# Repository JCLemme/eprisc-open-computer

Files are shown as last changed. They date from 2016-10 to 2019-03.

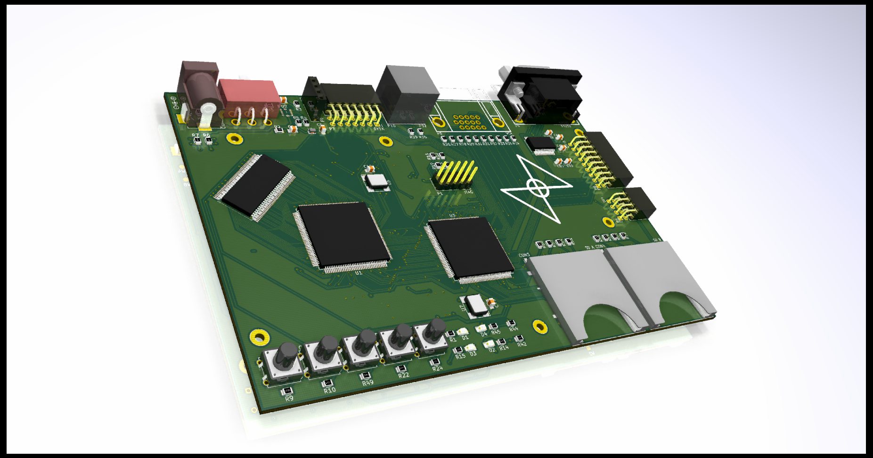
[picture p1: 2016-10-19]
hardware/eprisc_mach/eprisc_mach.png

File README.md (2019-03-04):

# epRISC Open Computer
An open-source computer

# **THIS REPO IS DEPRECATED - check out the "eprisc", "snag", "spasm", and "flail" repositories instead**

---

## Building things
Right now, the system testbench and the assembler can be compiled. Just run the provided Makefiles in their respective directories.

To build the system testbench, you'll need make, Icarus Verilog, and ideally some sort of waveform viewer (like GTKWave). The testbench emulates all of the system's I/O devices, but they aren't connected to anything, so you'll have to read the output waveforms yourself and determine if they're correct or not for debugging. Another thing to pay attention to is the length of time the testbench runs for; running the emulation long enough to catch rare problems might generate VCD files of several hundred megabytes.

To build spasm, you'll need g++, make, and libboost. Everything's been updated for the v5 ISA.

## Developing software
You can use spasm and the system testbench to develop software for the epRISC system. Documentation isn't complete for the new parts of the assembler, but you can use the code in the software/rom/ directory as a starting point. The full list of assembly instructions are in the .cpu file in the software/toolchain/spasm/ directory. 

The assembler can generate binaries in big-endian format and Verilog arrays. Run spasm with the -t flag, replace the contents of the array in the firmware/core/rom_v1r0.v file with the output file generated by spasm, and make the system testbench as directed above. 

## Running on hardware
A Quartus project is provided in the firmware/core directory to run the CPU and its peripherals on an Altera MAX 10 FPGA. You should be able, with little modification, to get the project to synthesize to another Altera FPGA or to another manufacturer's FPGA.

As of 04-05-2017, the computer is running successfully on its development board. If you're interested in running the system on your hardware, please contact me.

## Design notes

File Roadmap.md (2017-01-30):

# Things to do

## ISA
 * Finish defining advanced interrupt controller 
 * Define single-step/breakpoint unit
    
## Machine (Primary)
 * Define machine memory map
 * Write machine file
 * Write supporting I/O for machine file (mainly synchronous RAM/ROM)
 * Write machine testbench
 * Finish defining sysX
 * Write sysX master controller
 * Write sysX slave test unit (for testbench)

## I/O Controller (Auxiliary)
 * Write sysX slave controller
 * Write I/O controller core
 * Merge I/O controller into machine testbench
 * Write UART
 * Integrate UART into I/O controller

## Toolchain
 * Finish assembly format spec
 * Finish instruction set spec
 * Add !str, !pstr to spasm
 * Change !pc to !ip
 * Write ISA v5 core file
 * Retarget spasm to ISA v5 (general)

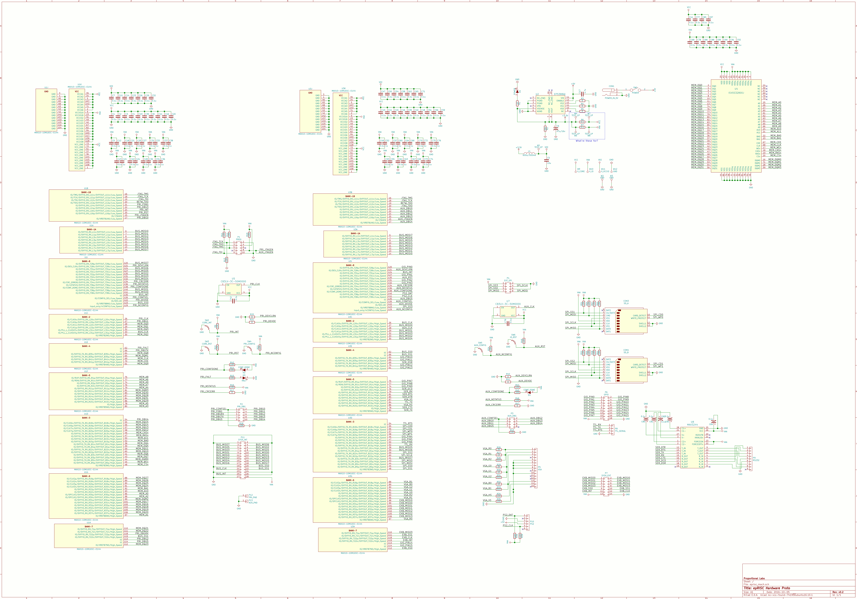
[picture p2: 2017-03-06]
hardware/eprisc_mach/pictureschem.svg/eprisc_mach.png

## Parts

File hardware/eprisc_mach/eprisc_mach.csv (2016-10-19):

Id | Designator | Package | Quantity | Designation | Supplier and ref
1 | C1,C2,C3,C4,C7,C8,C9,C10,C11,C13,C14,C16,C18,C19,C20,C22,C23,C25,C26,C28,C29,C31,C32,C34,C35,C37,C40,C42,C43,C44,C45,C46,C47,C48,C49,C50,C51,C53,C54,C56,C57,C58,C59,C61,C62,C64,C65,C67,C68,C70,C71,C73,C75,C78,C79,C80,C81,C82,C83,C84 | C_0805 | 60 | 0.1u
2 | C5 | C_0805 | 1 | 10u
3 | C6 | C_0805 | 1 | 47u/16v
4 | C12,C15,C21,C24,C27,C30,C33,C36,C38,C39,C41,C52,C55,C60,C63,C66,C69,C72,C74,C76,C77 | C_0805 | 21 | 1u
5 | C17 | C_0805 | 1 | 4.7u
6 | CON1 | BARREL_JACK | 1 | POWER_IN_5V
7 | CON2 | microsd_socket | 1 | SD_INT
8 | CON3 | SD_Card_Receptacle | 1 | SD_A
9 | CON4 | SD_Card_Receptacle | 1 | SD_B
10 | D1 | LED_0805 | 1 | GREEN
11 | D2,D4 | LED_0805 | 2 | CONF_DONE
12 | D3 | LED_0805 | 1 | HALT
13 | L1 | inductor_smd_4.8x2.8mm | 1 | 600o/500mA
14 | L2,L3 | inductor_smd_0805 | 2 | FERRITE_BEAD
15 | P5 | DB_15F-VGA | 1 | VGA
16 | P6 | Socket_Strip_Angled_2x09 | 1 | GPIO
17 | P7 | Socket_Strip_Angled_2x07 | 1 | SYSX_EXT
18 | P8 | Socket_Strip_Straight_1x04 | 1 | TTL_SERIAL
19 | P9 | DB_9F | 1 | RS232
20 | P10 | minidin-8 | 1 | PS2
21 | R1,R13,R14,R15,R16,R17,R27,R30,R32,R38,R45,R46,R47 | R_0805 | 13 | 1K
22 | R2 | R_0805 | 1 | DNI
23 | R3,R4,R5,R8,R20,R21,R23,R40,R41 | R_0805 | 9 | 0
24 | R6,R7 | R_0805 | 2 | 0.1
25 | R9,R10,R42,R44 | R_0805 | 4 | 3.3K
26 | R11,R12,R18,R19,R22,R24,R25,R36,R37,R39,R43,R48,R49 | R_0805 | 13 | 10K
27 | R26,R29 | R_0805 | 2 | 2K
28 | R28,R31,R33 | R_0805 | 3 | 510
29 | R34,R35 | R_0805 | 2 | 100
30 | R50,R51,R52,R53,R54,R55,R56,R57,R58,R59,R60,R61 | R_0805 | 12 | 50K
31 | SW2 | smd_push2 | 1 | CORE_INT
32 | SW3 | smd_push2 | 1 | CORE_RST
33 | SW4 | smd_push2 | 1 | PRI_CONFIG
34 | SW5 | smd_push2 | 1 | AUX_CONFIG
35 | SW6 | smd_push2 | 1 | IO_RST
36 | U1,U6 | LQFP-144_20x20mm_Pitch0.5mm | 2 | MAX10-10M16SA-E144
37 | U2 | QFN-16-ALTERA | 1 | EP5388QI
38 | U3 | SOT-23 | 1 | MCP1525
39 | U4 | TSOP-86 | 1 | IS45S32800J
40 | U5,U7 | CRYSTAL_CTS | 2 | CB3LV-3C-50M0000
41 | U8 | SSOP-28_5.3x10.2mm_Pitch0.65mm | 1 | MAX3244
42 | W1,W4,W5,W7,W8 | Measurement_Point_Round-SMD-Pad_Small | 5 | TEST_1P
43 | W2,W3,W6,W12 | Measurement_Point_Round-SMD-Pad_Small | 4 | GND
44 | W9 | Measurement_Point_Round-SMD-Pad_Small | 1 | V_CORE
45 | W10 | Measurement_Point_Round-SMD-Pad_Small | 1 | V_IO
46 | W11 | Measurement_Point_Round-SMD-Pad_Small | 1 | V_VCCIO
47 | W13 | Measurement_Point_Round-SMD-Pad_Small | 1 | GNDA
48 | W14 | Measurement_Point_Round-SMD-Pad_Small | 1 | V_REF
49 | P1 | SMD_STRIP_10 | 1 | PRI_PROG
50 | P2 | SMD_STRIP_10 | 1 | PRI_DBG
51 | P3 | SMD_STRIP_8 | 1 | AUX_DBG
52 | P4 | SMD_STRIP_10 | 1 | AUX_PROG
53 | P11 | SMD_STRIP_28 | 1 | SYSX_INT
54 | SW1 | SW_Micro_SPST_Angled | 1 | POWER

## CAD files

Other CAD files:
firmware/io/aux_project/output_files/stp1.stp

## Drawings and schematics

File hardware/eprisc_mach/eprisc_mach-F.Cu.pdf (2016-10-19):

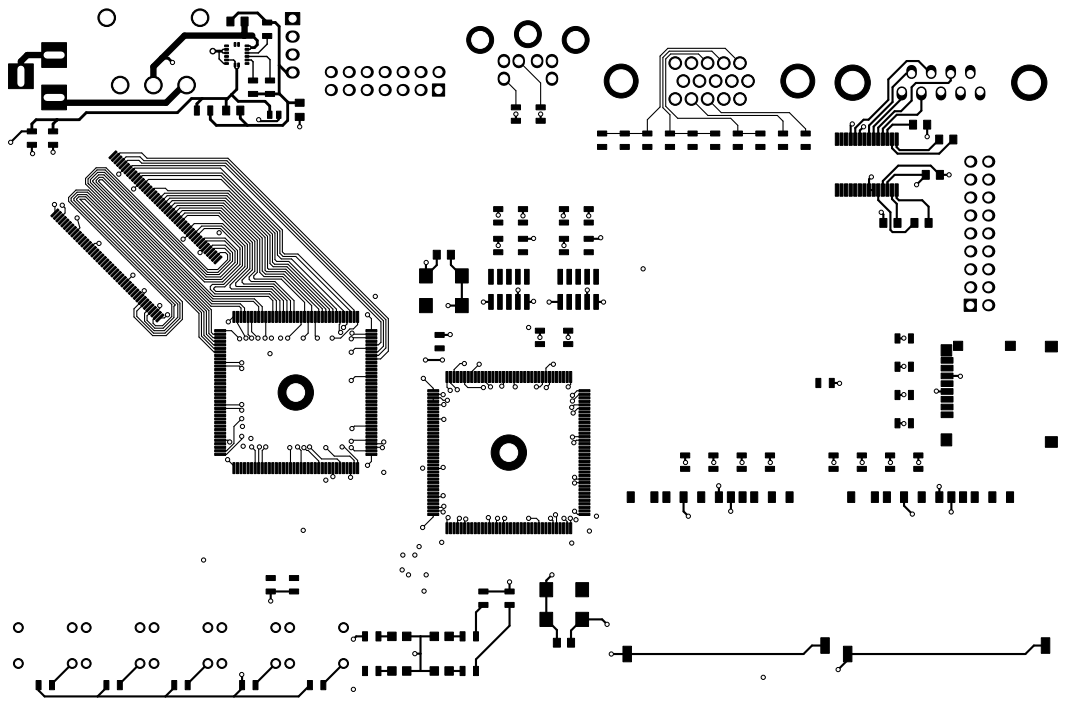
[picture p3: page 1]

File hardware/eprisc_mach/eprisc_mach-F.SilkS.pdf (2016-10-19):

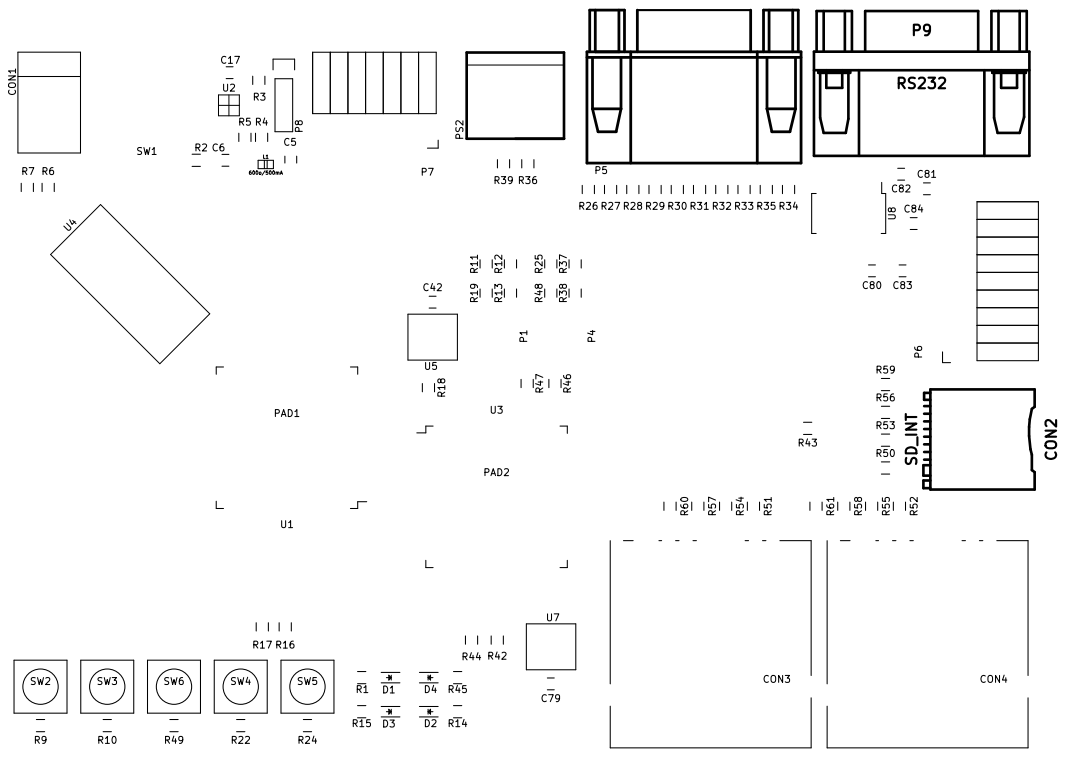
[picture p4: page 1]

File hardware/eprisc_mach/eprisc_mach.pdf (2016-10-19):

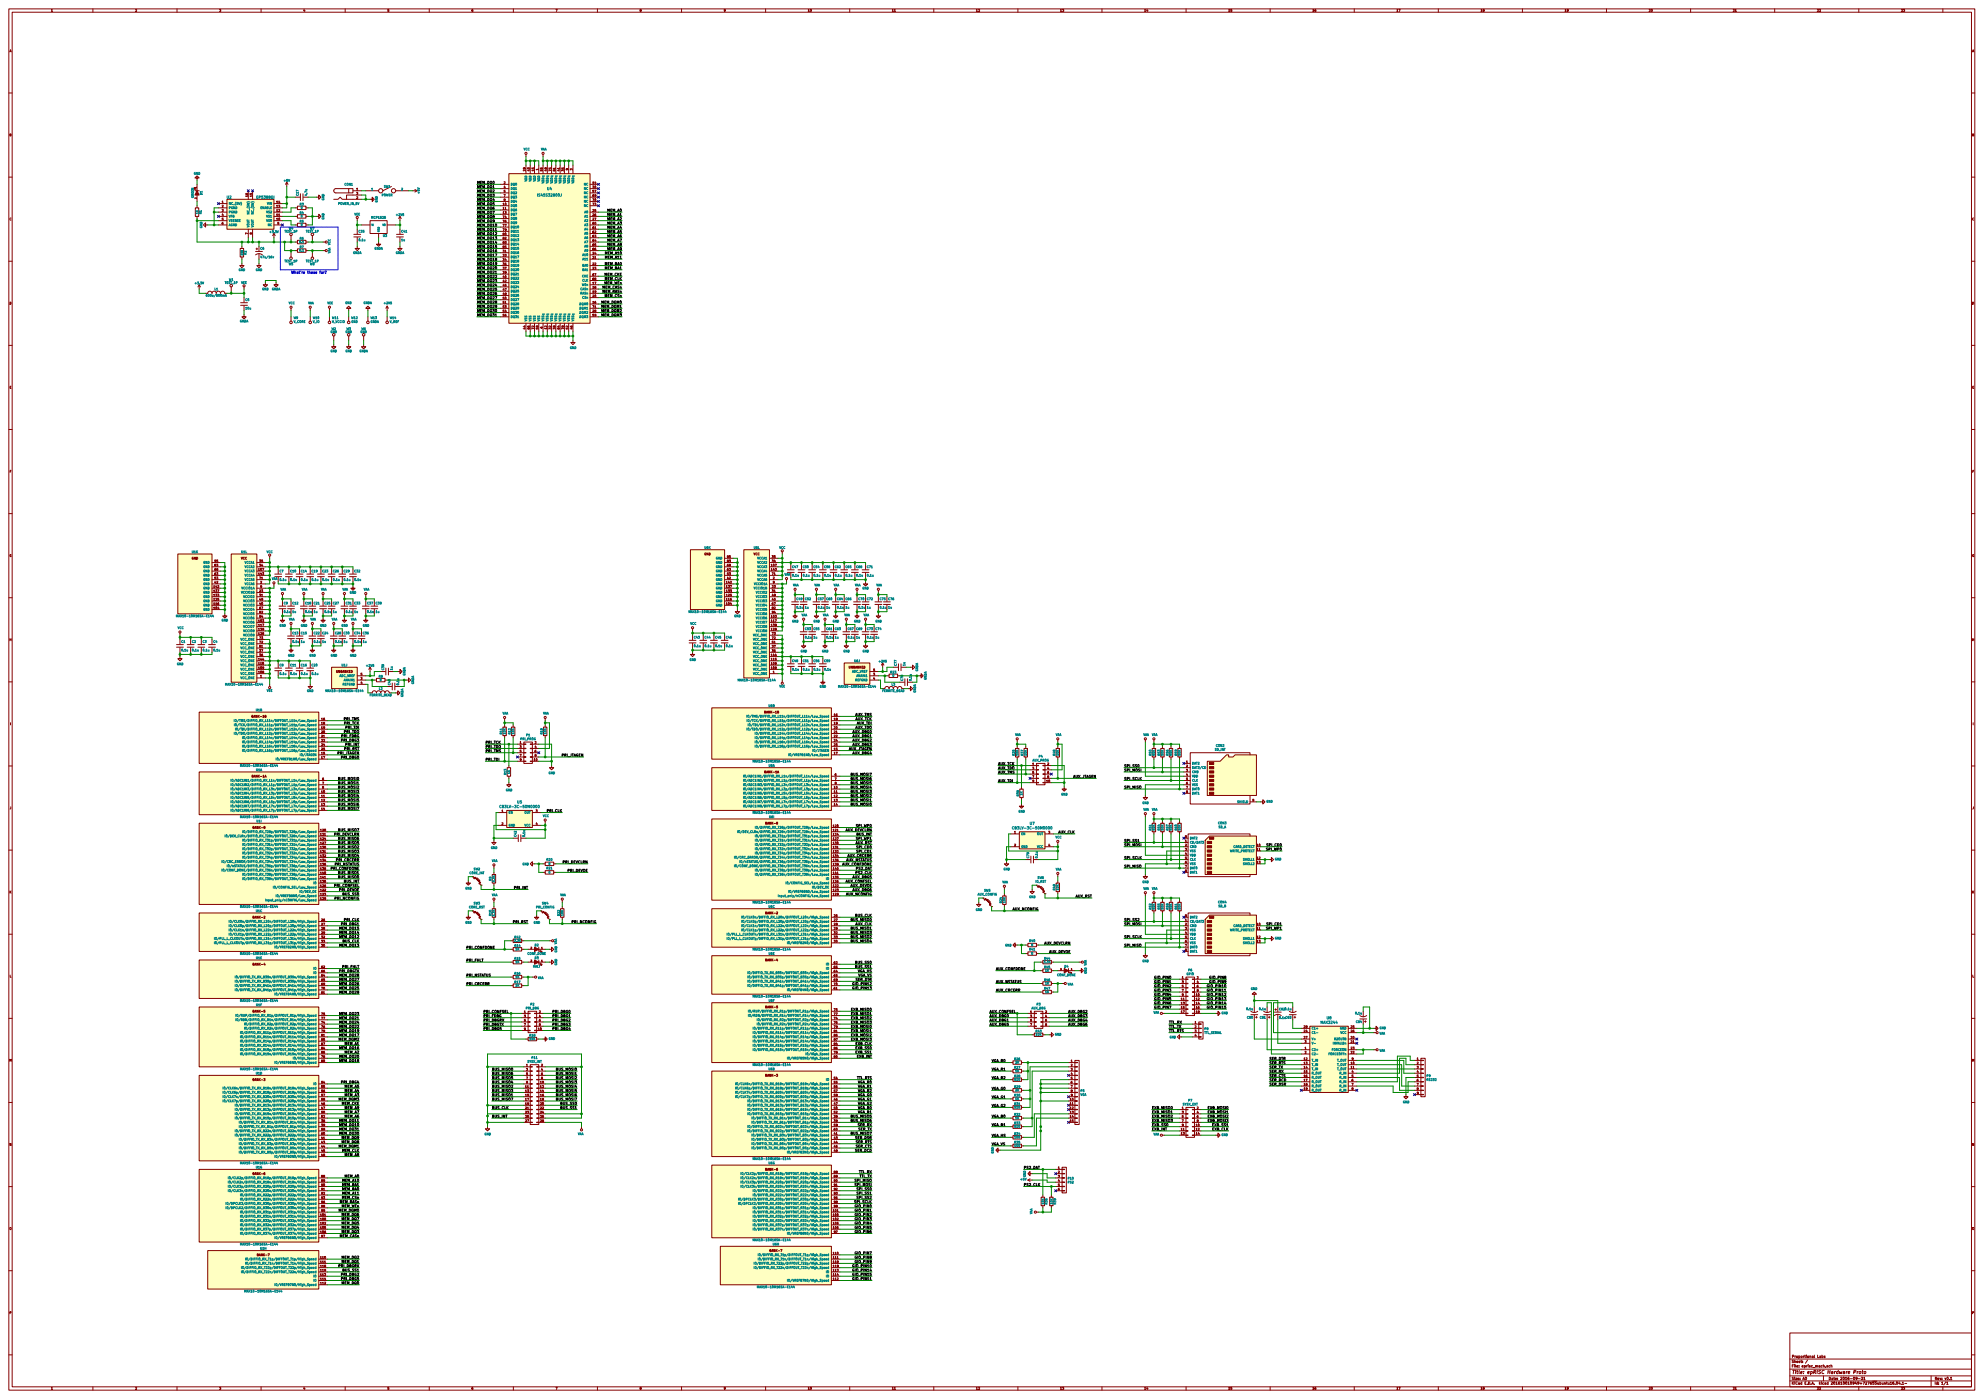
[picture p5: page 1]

File: eprisc_mach.sch Sheet: / Proportional Labs

Id: 1/1 Title: epRISC Hardware Proto

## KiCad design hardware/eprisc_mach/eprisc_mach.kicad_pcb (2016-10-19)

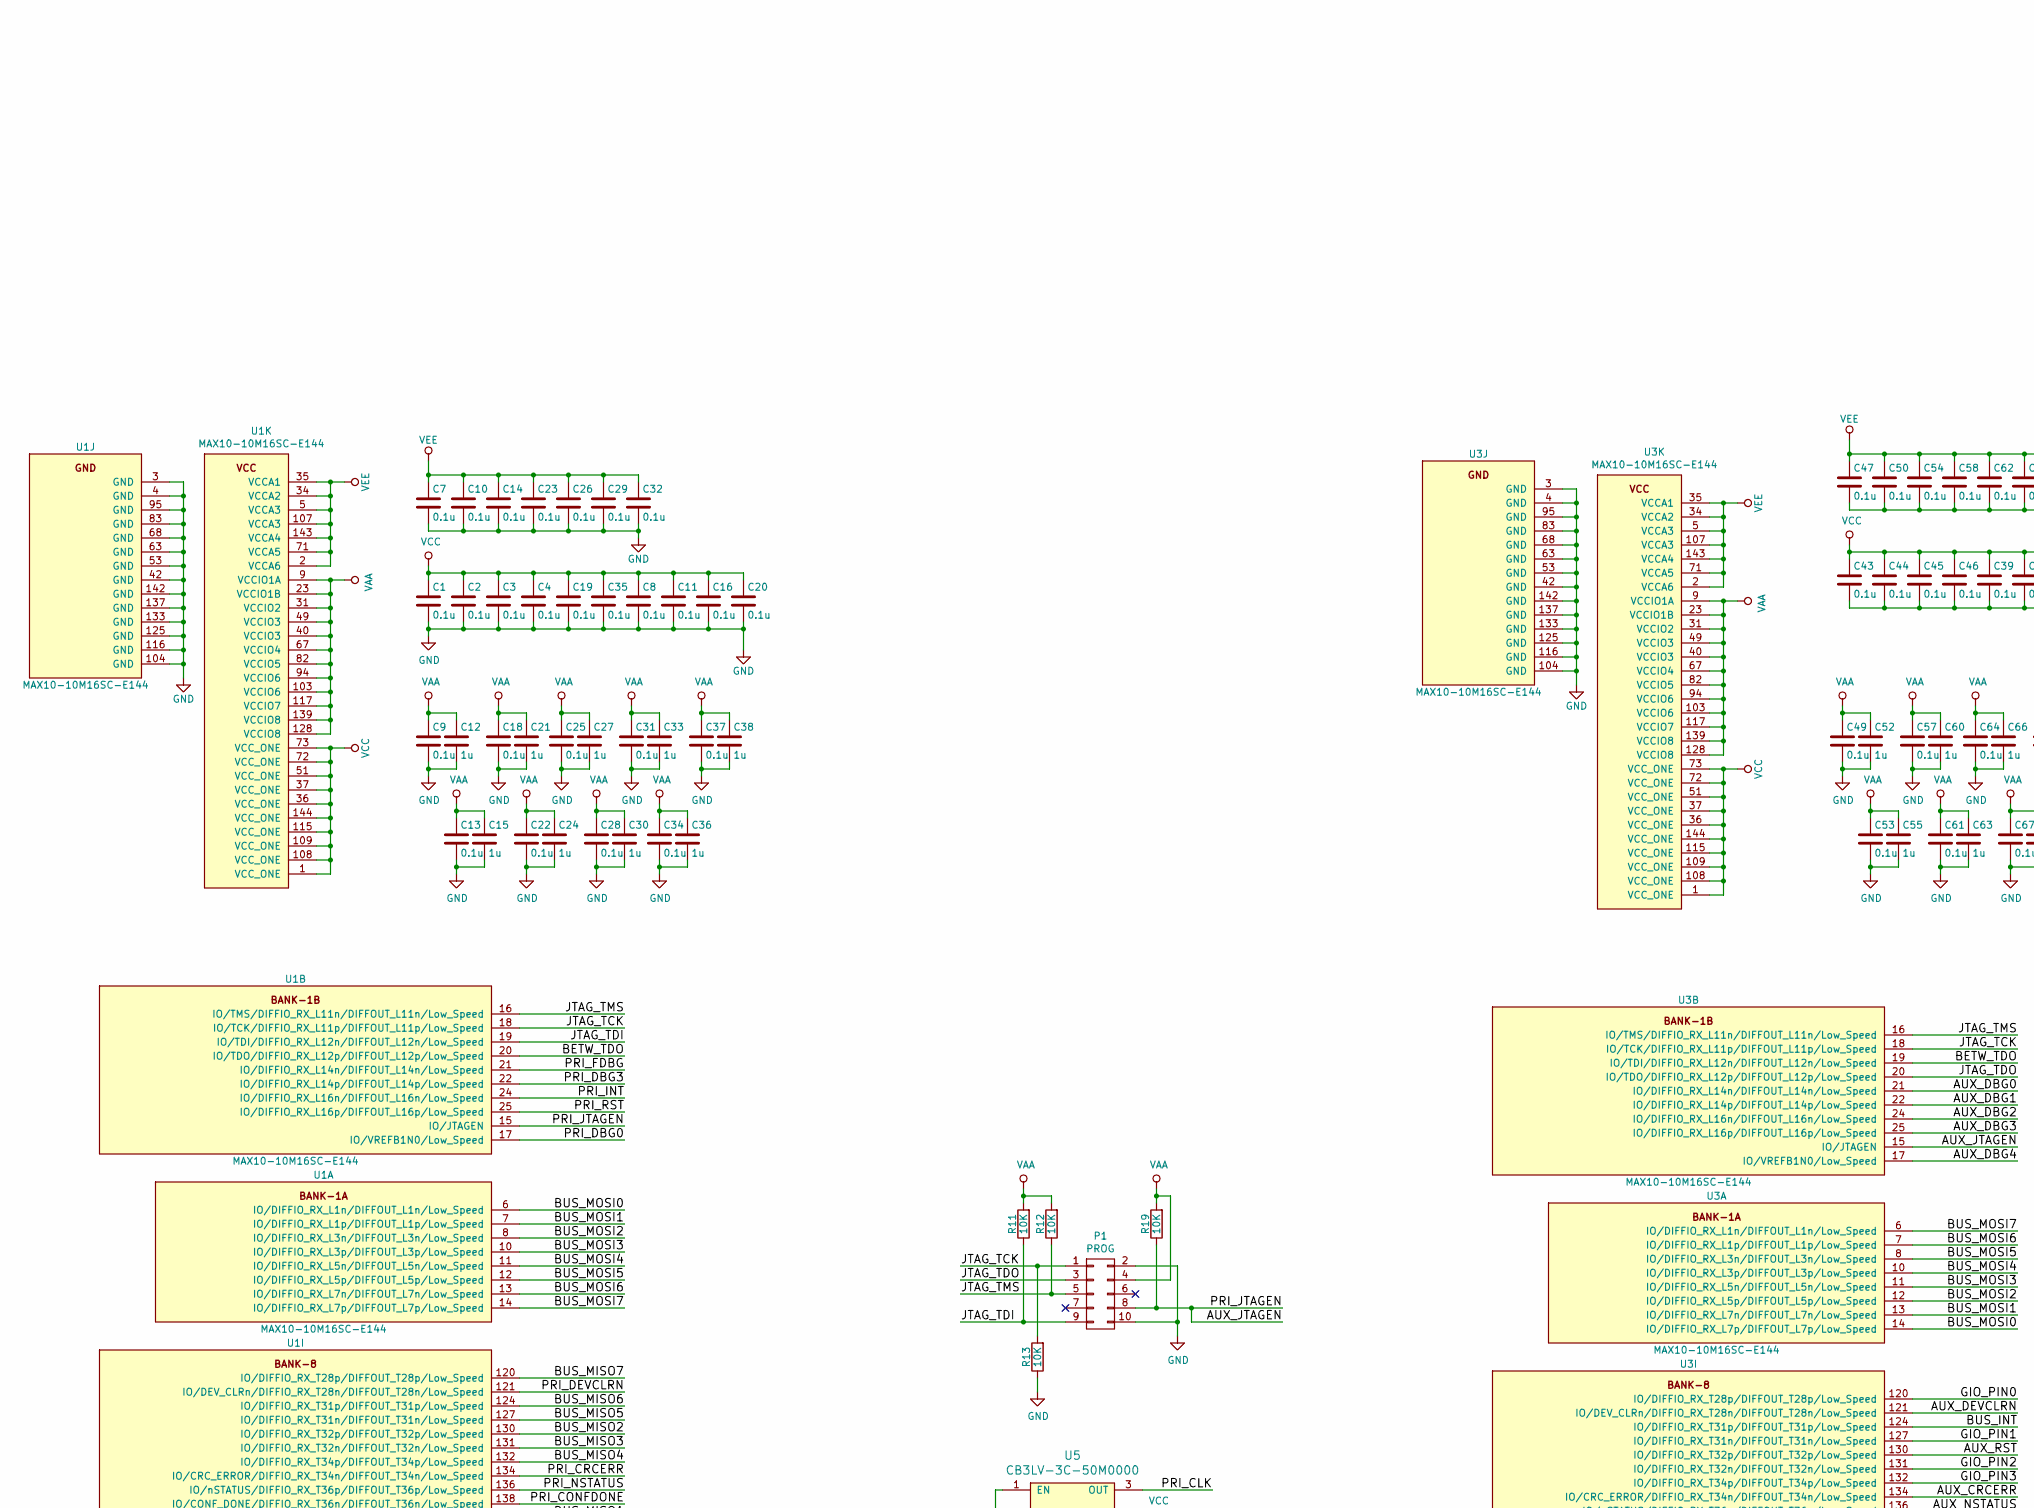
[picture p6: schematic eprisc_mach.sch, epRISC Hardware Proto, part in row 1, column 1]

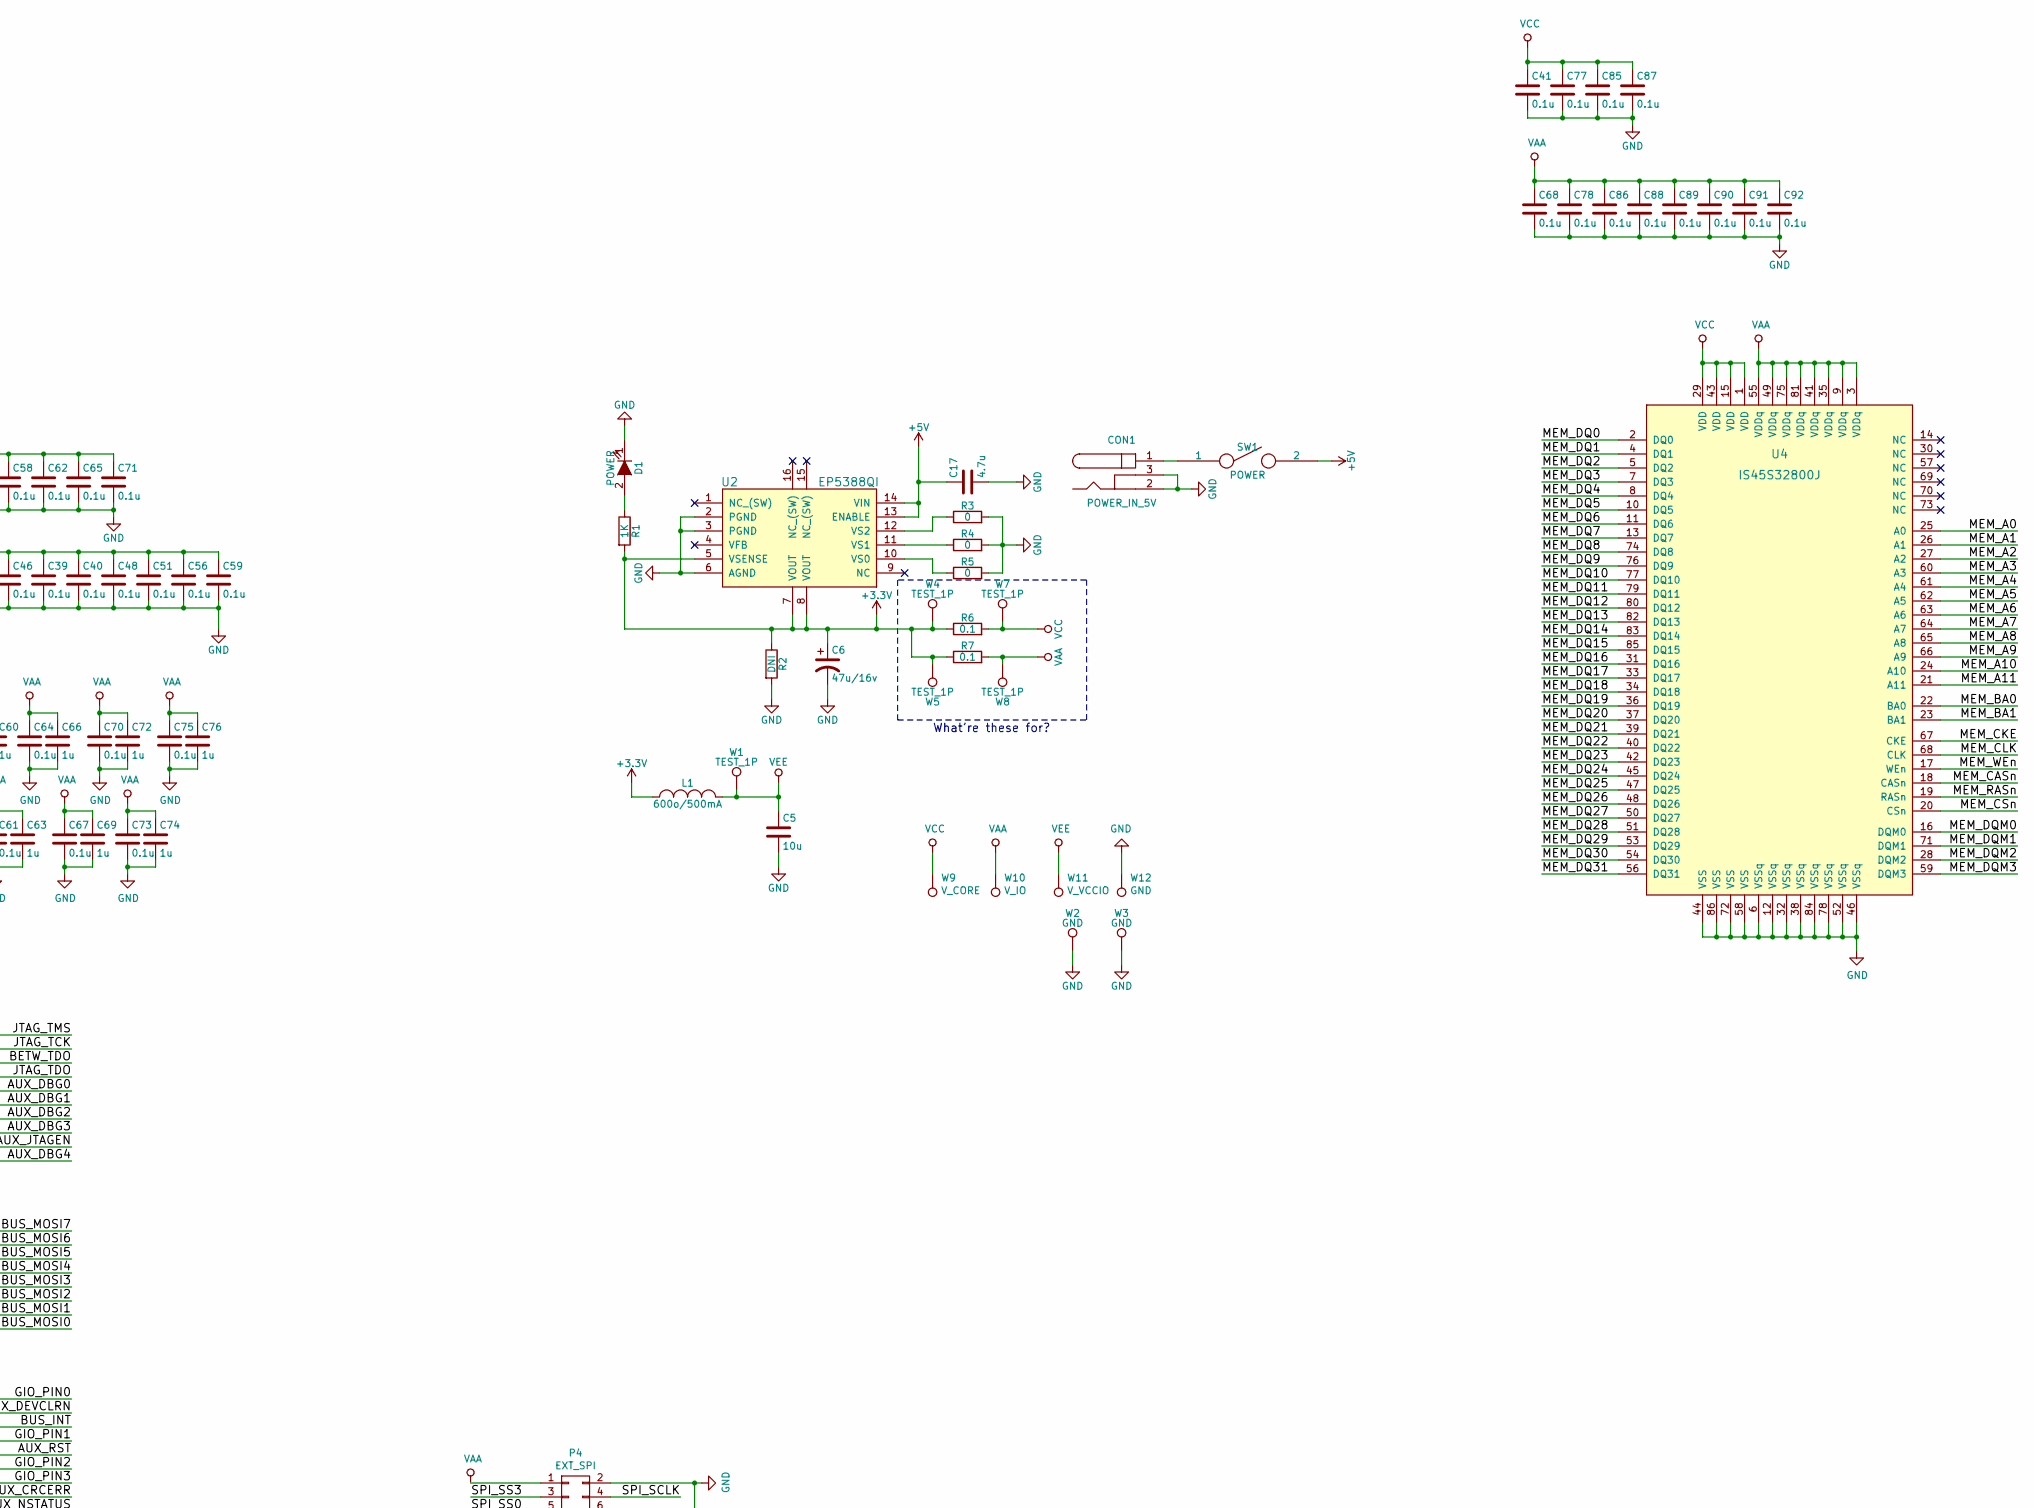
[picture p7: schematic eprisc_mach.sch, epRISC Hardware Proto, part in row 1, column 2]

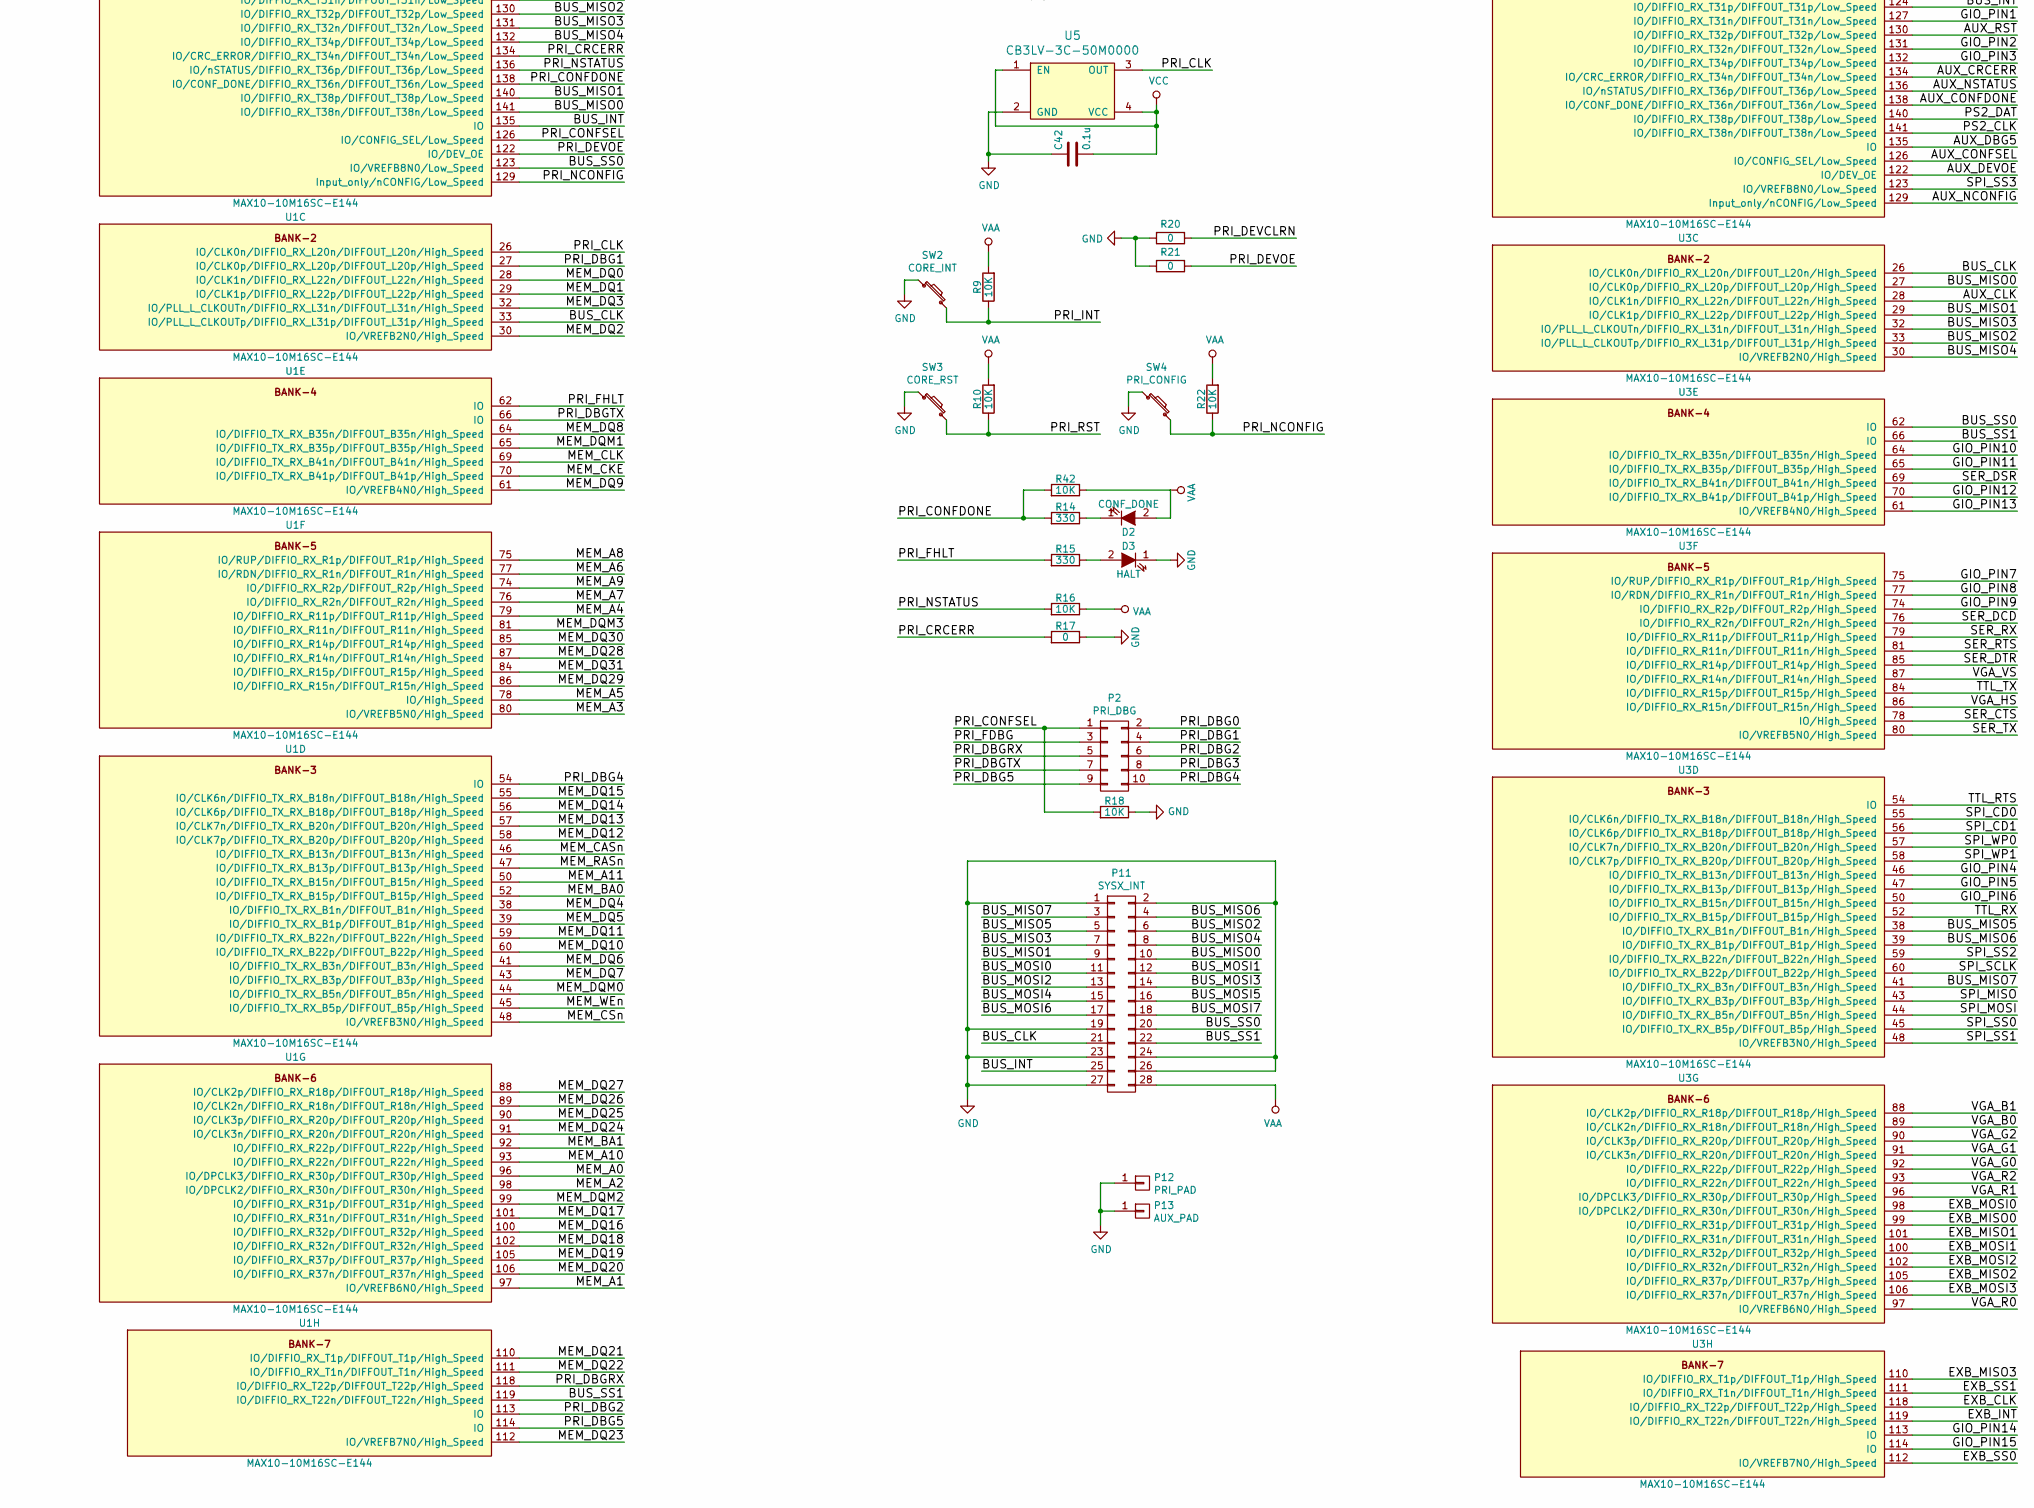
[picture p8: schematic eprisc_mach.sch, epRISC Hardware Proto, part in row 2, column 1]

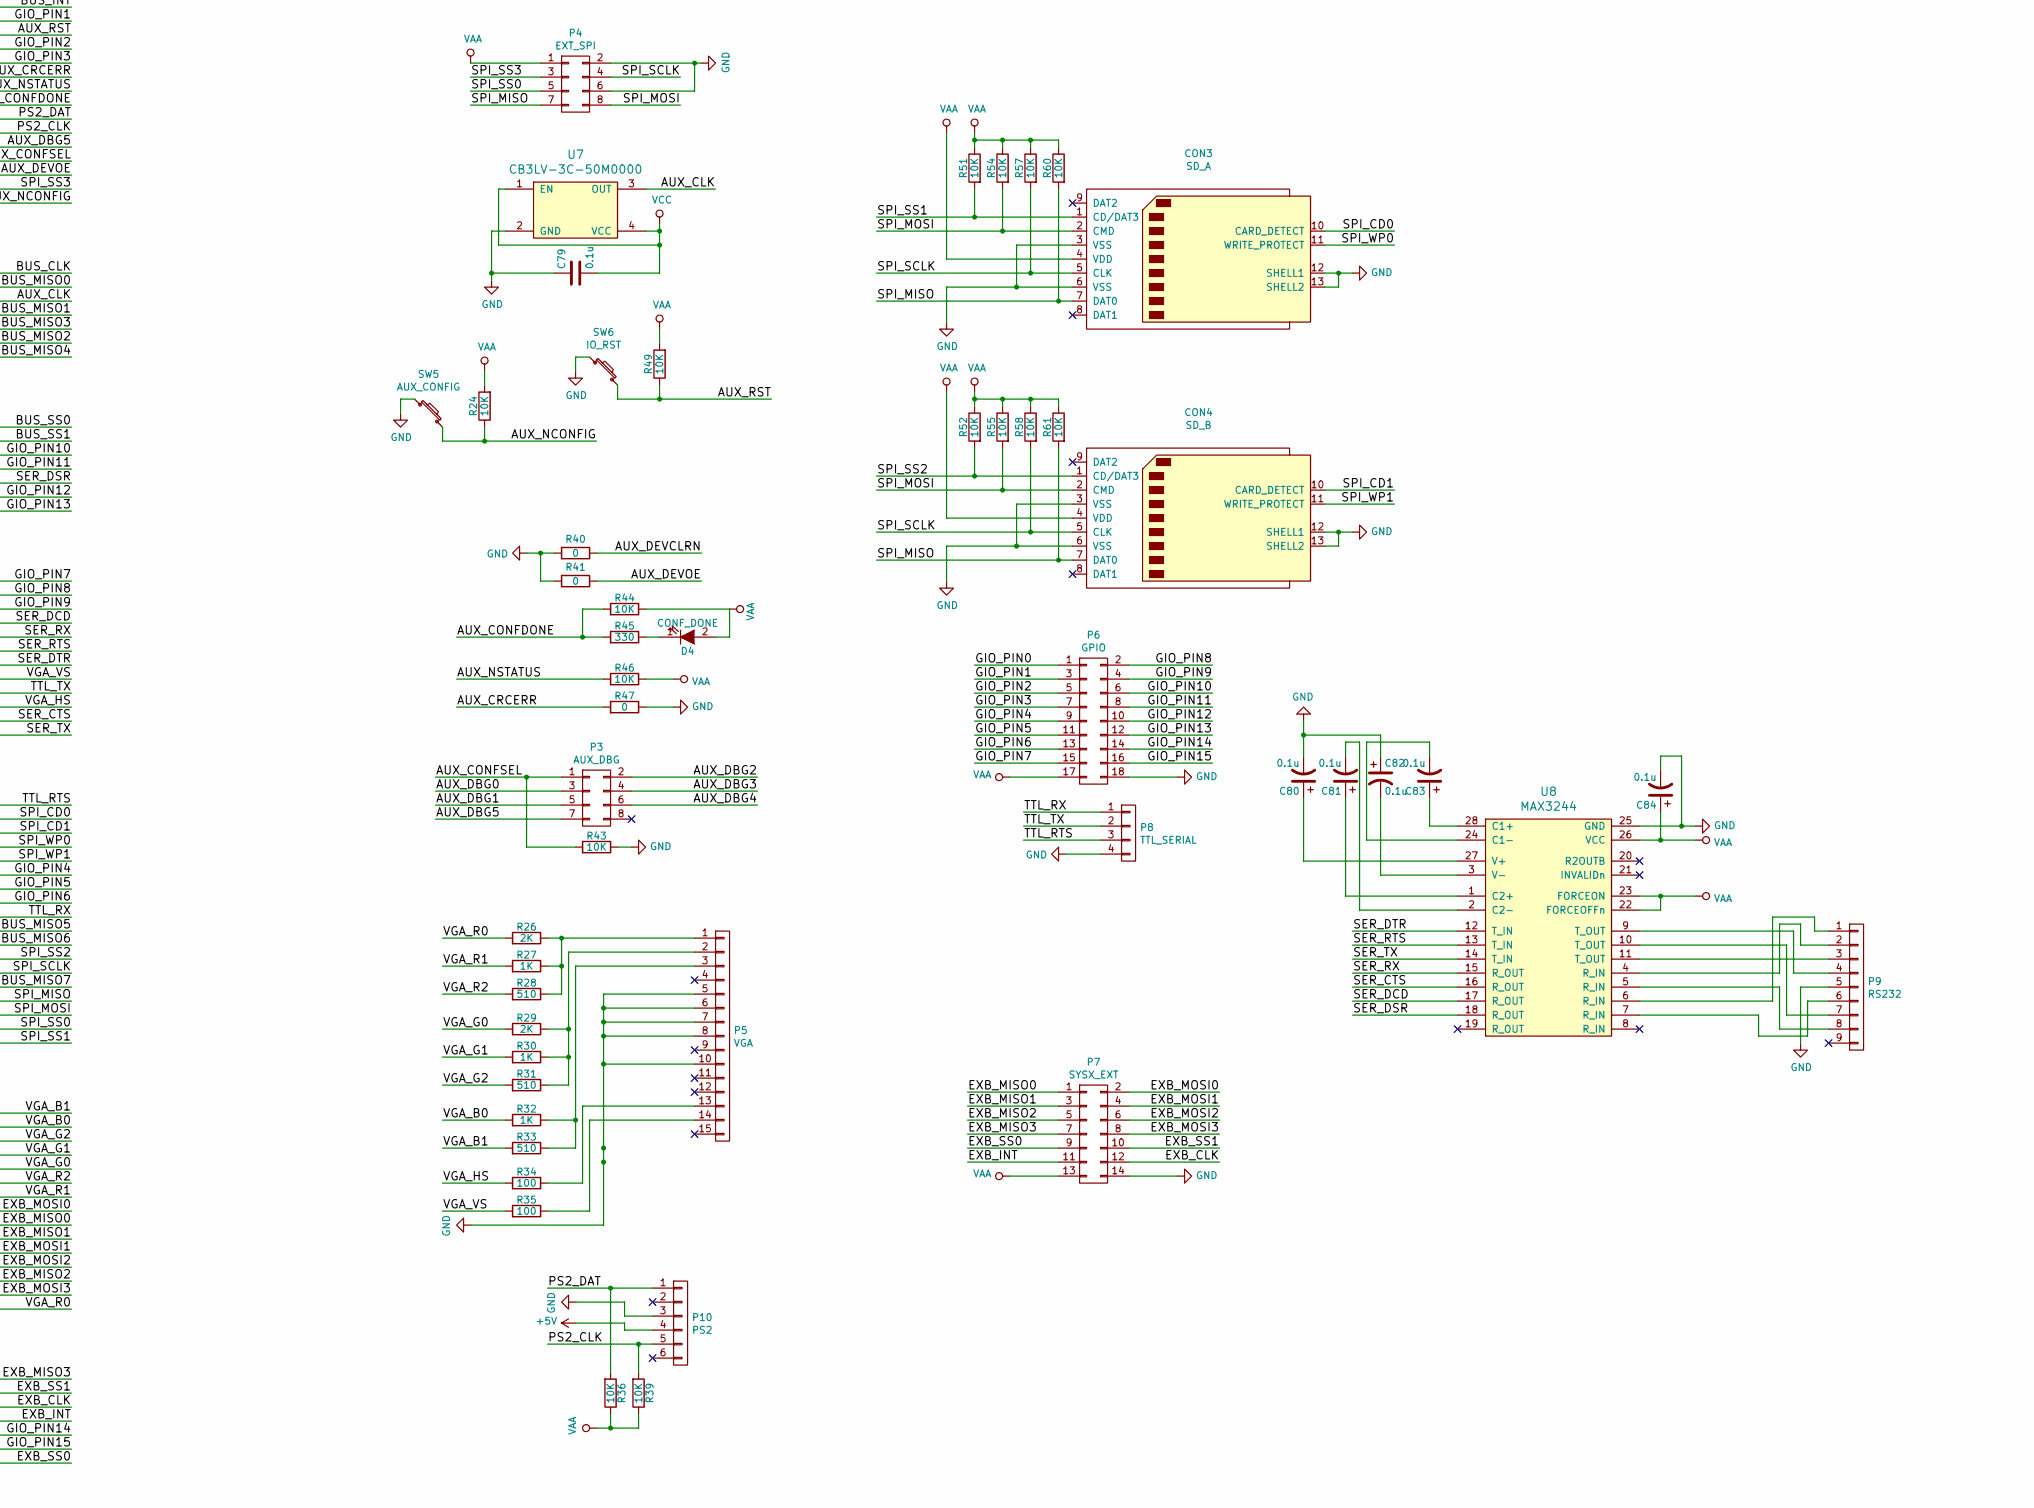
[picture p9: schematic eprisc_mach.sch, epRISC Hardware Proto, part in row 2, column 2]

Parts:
C1, C2, C3, C4, C7, C8, C9, C10, C11, C13, C14, C16, C18, C19, C20, C22, C23, C25, C26, C28, C29, C31, C32, C34, C35, C37, C39, C40, C41, C42, C43, C44, C45, C46, C47, C48, C49, C50, C51, C53, C54, C56, C57, C58, C59, C61, C62, C64, C65, C67, C68, C70, C71, C73, C75, C77, C78, C79, C80, C81, C82, C83, C84, C85, C86, C87, C88, C89, C90, C91, C92: 0.1u; C_0805
C5: 10u; C_0805
C6: 47u/16v; C_0805
C12, C15, C21, C24, C27, C30, C33, C36, C38, C52, C55, C60, C63, C66, C69, C72, C74, C76: 1u; C_0805
C17: 4.7u; C_0805
CON1: POWER_IN_5V; BARREL_JACK
CON3: SD_A; SD_Card_Receptacle
CON4: SD_B; SD_Card_Receptacle
D1: POWER; LED_0805
D2, D4: CONF_DONE; LED_0805
D3: HALT; LED_0805
L1: 600o/500mA; inductor_smd_0603
P1: PROG; Pin_Header_Straight_2x05
P2: PRI_DBG; SMD_STRIP_10
P3: AUX_DBG; SMD_STRIP_8
P4: EXT_SPI; Socket_Strip_Angled_2x04
P5: VGA; DB15F-VGA-AMP
P6: GPIO; Socket_Strip_Angled_2x09
P7: SYSX_EXT; Socket_Strip_Angled_2x07
P8: TTL_SERIAL; Socket_Strip_Straight_1x04
P9: RS232; DB_9F
P10: PS2; 00JG-MiniDin6
P11: SYSX_INT; SMD_STRIP_28
P12: PRI_PAD; MountingHole_2.5mm_Pad
P13: AUX_PAD; MountingHole_2.5mm_Pad
R1, R27, R30, R32: 1K; R_0805
R2: DNI; R_0805
R3, R4, R5, R17, R20, R21, R40, R41, R47: 0; R_0805
R6, R7: 0.1; R_0805
R9, R10, R11, R12, R13, R16, R18, R19, R22, R24, R36, R39, R42, R43, R44, R46, R49, R51, R52, R54, R55, R57, R58, R60, R61: 10K; R_0805
R14, R15, R45: 330; R_0805
R26, R29: 2K; R_0805
R28, R31, R33: 510; R_0805
R34, R35: 100; R_0805
SW1: POWER; SW_SLIDE_PWR
SW2: CORE_INT; SW_PUSH_SMALL
SW3: CORE_RST; SW_PUSH_SMALL
SW4: PRI_CONFIG; SW_PUSH_SMALL
SW5: AUX_CONFIG; SW_PUSH_SMALL
SW6: IO_RST; SW_PUSH_SMALL
U1, U3: MAX10-10M16SC-E144; LQFP-144_20x20mm_Pitch0.5mm
U2: EP5388QI; QFN-16-ALTERA
U4: IS45S32800J; TSOP-86
U5, U7: CB3LV-3C-50M0000; CRYSTAL_CTS
U8: MAX3244; SSOP-28_5.3x10.2mm_Pitch0.65mm
W1, W4, W5, W7, W8: TEST_1P; Measurement_Point_Round-SMD-Pad_Small
W2, W3, W12: GND; Measurement_Point_Round-SMD-Pad_Small
W9: V_CORE; Measurement_Point_Round-SMD-Pad_Small
W10: V_IO; Measurement_Point_Round-SMD-Pad_Small
W11: V_VCCIO; Measurement_Point_Round-SMD-Pad_Small

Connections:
+3V3: C6.1, L1.1, R1.2, R2.1, R6.1, R7.1, U2.5 (VSENSE), U2.7 (VOUT), U2.8 (VOUT), W4.1, W5.1
+5V: C17.1, P10.4, SW1.2, U2.13 (ENABLE), U2.14 (VIN)
/AUX_CLK: U3.28 (IO/CLK1n/DIFFIO_RX_L22n/DIFFOUT_L22n/Hi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), U7.3 (OUT)
/AUX_CONFDONE: R44.2, R45.2, U3.138 (IO/CONF_DONE/DIFFIO_RX_T36n/DIFFOUT_T36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)
/AUX_CONFSEL: P3.1, R43.2, U3.126 (IO/CONFIG_SEL/Low_Speed)
/AUX_CRCERR: R47.2, U3.134 (IO/CRC_ERROR/DIFFIO_RX_T34n/DIFFOUT_T34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)
/AUX_DBG0: P3.3, U3.21 (IO/DIFFIO_RX_L14n/DIFFOUT_L14n/Low_Speed)
/AUX_DBG1: P3.5, U3.22 (IO/DIFFIO_RX_L14p/DIFFOUT_L14p/Low_Speed)
/AUX_DBG2: P3.2, U3.24 (IO/DIFFIO_RX_L16n/DIFFOUT_L16n/Low_Speed)
/AUX_DBG3: P3.4, U3.25 (IO/DIFFIO_RX_L16p/DIFFOUT_L16p/Low_Speed)
/AUX_DBG4: P3.6, U3.17 (IO/VREFB1N0/Low_Speed)
/AUX_DBG5: P3.7, U3.135 (IO)
/AUX_DEVCLRN: R40.1, U3.121 (IO/DEV_CLRn/DIFFIO_RX_T28n/DIFFOUT_T28n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)
/AUX_DEVOE: R41.1, U3.122 (IO/DEV_OE)
/AUX_JTAGEN: P1.8, R19.1, U1.15 (IO/JTAGEN), U3.15 (IO/JTAGEN)
/AUX_NCONFIG: R24.1, SW5.2, U3.129 (Input_only/nCONFIG/Low_Speed)
/AUX_NSTATUS: R46.2, U3.136 (IO/nSTATUS/DIFFIO_RX_T36p/DIFFOUT_T36p/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)
/AUX_RST: R49.1, SW6.2, U3.130 (IO/DIFFIO_RX_T32p/DIFFOUT_T32p/Low_Speed)
/BETW_TDO: U1.20 (IO/TDO/DIFFIO_RX_L12p/DIFFOUT_L12p/Low_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), U3.19 (IO/TDI/DIFFIO_RX_L12n/DIFFOUT_L12n/Low_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)
/BUS_CLK: P11.21, U1.33 (IO/PLL_L_CLKOUTp/DIFFIO_RX_L31p/DIFFOUT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), U3.26 (IO/CLK0n/DIFFIO_RX_L20n/DIFFOUT_L20n/Hi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)
/BUS_INT: P11.25, U1.135 (IO), U3.124 (IO/DIFFIO_RX_T31p/DIFFOUT_T31p/Low_Speed)
/BUS_MISO0: P11.10, U1.141 (IO/DIFFIO_RX_T38n/DIFFOUT_T38n/Low_Speed), U3.27 (IO/CLK0p/DIFFIO_RX_L20p/DIFFOUT_L20p/Hi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)
/BUS_MISO1: P11.9, U1.140 (IO/DIFFIO_RX_T38p/DIFFOUT_T38p/Low_Speed), U3.29 (IO/CLK1p/DIFFIO_RX_L22p/DIFFOUT_L22p/Hi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)
/BUS_MISO2: P11.6, U1.130 (IO/DIFFIO_RX_T32p/DIFFOUT_T32p/Low_Speed), U3.33 (IO/PLL_L_CLKOUTp/DIFFIO_RX_L31p/DIFFOUT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)
/BUS_MISO3: P11.7, U1.131 (IO/DIFFIO_RX_T32n/DIFFOUT_T32n/Low_Speed), U3.32 (IO/PLL_L_CLKOUTn/DIFFIO_RX_L31n/DIFFOUT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)
/BUS_MISO4: P11.8, U1.132 (IO/DIFFIO_RX_T34p/DIFFOUT_T34p/Low_Speed), U3.30 (IO/VREFB2N0/High_Speed)
/BUS_MISO5: P11.5, U1.127 (IO/DIFFIO_RX_T31n/DIFFOUT_T31n/Low_Speed), U3.38 (IO/DIFFIO_TX_RX_B1n/DIFFOUT_B1n/High_Sp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)
/BUS_MISO6: P11.4, U1.124 (IO/DIFFIO_RX_T31p/DIFFOUT_T31p/Low_Speed), U3.39 (IO/DIFFIO_TX_RX_B1p/DIFFOUT_B1p/High_Sp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)
/BUS_MISO7: P11.3, U1.120 (IO/DIFFIO_RX_T28p/DIFFOUT_T28p/Low_Speed), U3.41 (IO/DIFFIO_TX_RX_B3n/DIFFOUT_B3n/High_Sp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)
/BUS_MOSI0: P11.11, U1.6 (IO/DIFFIO_RX_L1n/DIFFOUT_L1n/Low_Speed), U3.14 (IO/DIFFIO_RX_L7p/DIFFOUT_L7p/Low_Speed)
/BUS_MOSI1: P11.12, U1.7 (IO/DIFFIO_RX_L1p/DIFFOUT_L1p/Low_Speed), U3.13 (IO/DIFFIO_RX_L7n/DIFFOUT_L7n/Low_Speed)
/BUS_MOSI2: P11.13, U1.8 (IO/DIFFIO_RX_L3n/DIFFOUT_L3n/Low_Speed), U3.12 (IO/DIFFIO_RX_L5p/DIFFOUT_L5p/Low_Speed)
/BUS_MOSI3: P11.14, U1.10 (IO/DIFFIO_RX_L3p/DIFFOUT_L3p/Low_Speed), U3.11 (IO/DIFFIO_RX_L5n/DIFFOUT_L5n/Low_Speed)
/BUS_MOSI4: P11.15, U1.11 (IO/DIFFIO_RX_L5n/DIFFOUT_L5n/Low_Speed), U3.10 (IO/DIFFIO_RX_L3p/DIFFOUT_L3p/Low_Speed)
/BUS_MOSI5: P11.16, U1.12 (IO/DIFFIO_RX_L5p/DIFFOUT_L5p/Low_Speed), U3.8 (IO/DIFFIO_RX_L3n/DIFFOUT_L3n/Low_Speed)
/BUS_MOSI6: P11.17, U1.13 (IO/DIFFIO_RX_L7n/DIFFOUT_L7n/Low_Speed), U3.7 (IO/DIFFIO_RX_L1p/DIFFOUT_L1p/Low_Speed)
/BUS_MOSI7: P11.18, U1.14 (IO/DIFFIO_RX_L7p/DIFFOUT_L7p/Low_Speed), U3.6 (IO/DIFFIO_RX_L1n/DIFFOUT_L1n/Low_Speed)
/BUS_SS0: P11.20, U1.123 (IO/VREFB8N0/Low_Speed), U3.62 (IO)
/BUS_SS1: P11.22, U1.119 (IO/DIFFIO_RX_T22n/DIFFOUT_T22n/High_Spe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), U3.66 (IO)
/EXB_CLK: P7.12, U3.118 (IO/DIFFIO_RX_T22p/DIFFOUT_T22p/High_Spe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)
/EXB_INT: P7.11, U3.119 (IO/DIFFIO_RX_T22n/DIFFOUT_T22n/High_Spe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)
/EXB_MISO0: P7.1, U3.99 (IO/DIFFIO_RX_R31p/DIFFOUT_R31p/High_Spe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)
/EXB_MISO1: P7.3, U3.101 (IO/DIFFIO_RX_R31n/DIFFOUT_R31n/High_Spe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)
/EXB_MISO2: P7.5, U3.105 (IO/DIFFIO_RX_R37p/DIFFOUT_R37p/High_Spe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)
/EXB_MISO3: P7.7, U3.110 (IO/DIFFIO_RX_T1p/DIFFOUT_T1p/High_Speed)
/EXB_MOSI0: P7.2, U3.98 (IO/DPCLK2/DIFFIO_RX_R30n/DIFFOUT_R30n/H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)
/EXB_MOSI1: P7.4, U3.100 (IO/DIFFIO_RX_R32p/DIFFOUT_R32p/High_Spe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)
/EXB_MOSI2: P7.6, U3.102 (IO/DIFFIO_RX_R32n/DIFFOUT_R32n/High_Spe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)
/EXB_MOSI3: P7.8, U3.106 (IO/DIFFIO_RX_R37n/DIFFOUT_R37n/High_Spe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)
/EXB_SS0: P7.9, U3.112 (IO/VREFB7N0/High_Speed)
/EXB_SS1: P7.10, U3.111 (IO/DIFFIO_RX_T1n/DIFFOUT_T1n/High_Speed)
/GIO_PIN0: P6.1, U3.120 (IO/DIFFIO_RX_T28p/DIFFOUT_T28p/Low_Speed)
/GIO_PIN1: P6.3, U3.127 (IO/DIFFIO_RX_T31n/DIFFOUT_T31n/Low_Speed)
/GIO_PIN2: P6.5, U3.131 (IO/DIFFIO_RX_T32n/DIFFOUT_T32n/Low_Speed)
/GIO_PIN3: P6.7, U3.132 (IO/DIFFIO_RX_T34p/DIFFOUT_T34p/Low_Speed)
/GIO_PIN4: P6.9, U3.46 (IO/DIFFIO_TX_RX_B13n/DIFFOUT_B13n/High_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)
/GIO_PIN5: P6.11, U3.47 (IO/DIFFIO_TX_RX_B13p/DIFFOUT_B13p/High_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)
/GIO_PIN6: P6.13, U3.50 (IO/DIFFIO_TX_RX_B15n/DIFFOUT_B15n/High_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)
/GIO_PIN7: P6.15, U3.75 (IO/RUP/DIFFIO_RX_R1p/DIFFOUT_R1p/High_S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)
/GIO_PIN8: P6.2, U3.77 (IO/RDN/DIFFIO_RX_R1n/DIFFOUT_R1n/High_S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)
/GIO_PIN9: P6.4, U3.74 (IO/DIFFIO_RX_R2p/DIFFOUT_R2p/High_Speed)
/GIO_PIN10: P6.6, U3.64 (IO/DIFFIO_TX_RX_B35n/DIFFOUT_B35n/High_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)
/GIO_PIN11: P6.8, U3.65 (IO/DIFFIO_TX_RX_B35p/DIFFOUT_B35p/High_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)
/GIO_PIN12: P6.10, U3.70 (IO/DIFFIO_TX_RX_B41p/DIFFOUT_B41p/High_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)
/GIO_PIN13: P6.12, U3.61 (IO/VREFB4N0/High_Speed)
/GIO_PIN14: P6.14, U3.113 (IO)
/GIO_PIN15: P6.16, U3.114 (IO)
/JTAG_TCK: P1.1, R13.2, U1.18 (IO/TCK/DIFFIO_RX_L11p/DIFFOUT_L11p/Low_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), U3.18 (IO/TCK/DIFFIO_RX_L11p/DIFFOUT_L11p/Low_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)
/JTAG_TDI: P1.9, R11.1, U1.19 (IO/TDI/DIFFIO_RX_L12n/DIFFOUT_L12n/Low_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)
/JTAG_TDO: P1.3, U3.20 (IO/TDO/DIFFIO_RX_L12p/DIFFOUT_L12p/Low_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)
/JTAG_TMS: P1.5, R12.1, U1.16 (IO/TMS/DIFFIO_RX_L11n/DIFFOUT_L11n/Low_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), U3.16 (IO/TMS/DIFFIO_RX_L11n/DIFFOUT_L11n/Low_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)
/MEM_A0: U1.96 (IO/DPCLK3/DIFFIO_RX_R30p/DIFFOUT_R30p/H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), U4.25 (A0)
/MEM_A1: U1.97 (IO/VREFB6N0/High_Speed), U4.26 (A1)
/MEM_A2: U1.98 (IO/DPCLK2/DIFFIO_RX_R30n/DIFFOUT_R30n/H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), U4.27 (A2)
/MEM_A3: U1.80 (IO/VREFB5N0/High_Speed), U4.60 (A3)
/MEM_A4: U1.79 (IO/DIFFIO_RX_R11p/DIFFOUT_R11p/High_Spe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), U4.61 (A4)
/MEM_A5: U1.78 (IO/High_Speed), U4.62 (A5)
/MEM_A6: U1.77 (IO/RDN/DIFFIO_RX_R1n/DIFFOUT_R1n/High_S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), U4.63 (A6)
/MEM_A7: U1.76 (IO/DIFFIO_RX_R2n/DIFFOUT_R2n/High_Speed), U4.64 (A7)
/MEM_A8: U1.75 (IO/RUP/DIFFIO_RX_R1p/DIFFOUT_R1p/High_S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), U4.65 (A8)
/MEM_A9: U1.74 (IO/DIFFIO_RX_R2p/DIFFOUT_R2p/High_Speed), U4.66 (A9)
/MEM_A10: U1.93 (IO/DIFFIO_RX_R22n/DIFFOUT_R22n/High_Spe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), U4.24 (A10)
/MEM_A11: U1.50 (IO/DIFFIO_TX_RX_B15n/DIFFOUT_B15n/High_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), U4.21 (A11)
/MEM_BA0: U1.52 (IO/DIFFIO_TX_RX_B15p/DIFFOUT_B15p/High_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), U4.22 (BA0)
/MEM_BA1: U1.92 (IO/DIFFIO_RX_R22p/DIFFOUT_R22p/High_Spe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), U4.23 (BA1)
/MEM_CASn: U1.46 (IO/DIFFIO_TX_RX_B13n/DIFFOUT_B13n/High_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), U4.18 (CASn)
/MEM_CKE: U1.70 (IO/DIFFIO_TX_RX_B41p/DIFFOUT_B41p/High_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), U4.67 (CKE)
/MEM_CLK: U1.69 (IO/DIFFIO_TX_RX_B41n/DIFFOUT_B41n/High_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), U4.68 (CLK)
/MEM_CSn: U1.48 (IO/VREFB3N0/High_Speed), U4.20 (CSn)
/MEM_DQ0: U1.28 (IO/CLK1n/DIFFIO_RX_L22n/DIFFOUT_L22n/Hi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), U4.2 (DQ0)
/MEM_DQ1: U1.29 (IO/CLK1p/DIFFIO_RX_L22p/DIFFOUT_L22p/Hi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), U4.4 (DQ1)
/MEM_DQ2: U1.30 (IO/VREFB2N0/High_Speed), U4.5 (DQ2)
/MEM_DQ3: U1.32 (IO/PLL_L_CLKOUTn/DIFFIO_RX_L31n/DIFFOUT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), U4.7 (DQ3)
/MEM_DQ4: U1.38 (IO/DIFFIO_TX_RX_B1n/DIFFOUT_B1n/High_Sp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), U4.8 (DQ4)
/MEM_DQ5: U1.39 (IO/DIFFIO_TX_RX_B1p/DIFFOUT_B1p/High_Sp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), U4.10 (DQ5)
/MEM_DQ6: U1.41 (IO/DIFFIO_TX_RX_B3n/DIFFOUT_B3n/High_Sp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), U4.11 (DQ6)
/MEM_DQ7: U1.43 (IO/DIFFIO_TX_RX_B3p/DIFFOUT_B3p/High_Sp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), U4.13 (DQ7)
/MEM_DQ8: U1.64 (IO/DIFFIO_TX_RX_B35n/DIFFOUT_B35n/High_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), U4.74 (DQ8)
/MEM_DQ9: U1.61 (IO/VREFB4N0/High_Speed), U4.76 (DQ9)
/MEM_DQ10: U1.60 (IO/DIFFIO_TX_RX_B22p/DIFFOUT_B22p/High_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), U4.77 (DQ10)
/MEM_DQ11: U1.59 (IO/DIFFIO_TX_RX_B22n/DIFFOUT_B22n/High_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), U4.79 (DQ11)
/MEM_DQ12: U1.58 (IO/CLK7p/DIFFIO_TX_RX_B20p/DIFFOUT_B20p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), U4.80 (DQ12)
/MEM_DQ13: U1.57 (IO/CLK7n/DIFFIO_TX_RX_B20n/DIFFOUT_B20n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), U4.82 (DQ13)
/MEM_DQ14: U1.56 (IO/CLK6p/DIFFIO_TX_RX_B18p/DIFFOUT_B18p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), U4.83 (DQ14)
/MEM_DQ15: U1.55 (IO/CLK6n/DIFFIO_TX_RX_B18n/DIFFOUT_B18n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), U4.85 (DQ15)
/MEM_DQ16: U1.100 (IO/DIFFIO_RX_R32p/DIFFOUT_R32p/High_Spe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), U4.31 (DQ16)
/MEM_DQ17: U1.101 (IO/DIFFIO_RX_R31n/DIFFOUT_R31n/High_Spe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), U4.33 (DQ17)
/MEM_DQ18: U1.102 (IO/DIFFIO_RX_R32n/DIFFOUT_R32n/High_Spe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), U4.34 (DQ18)
/MEM_DQ19: U1.105 (IO/DIFFIO_RX_R37p/DIFFOUT_R37p/High_Spe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), U4.36 (DQ19)
/MEM_DQ20: U1.106 (IO/DIFFIO_RX_R37n/DIFFOUT_R37n/High_Spe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), U4.37 (DQ20)
/MEM_DQ21: U1.110 (IO/DIFFIO_RX_T1p/DIFFOUT_T1p/High_Speed), U4.39 (DQ21)
/MEM_DQ22: U1.111 (IO/DIFFIO_RX_T1n/DIFFOUT_T1n/High_Speed), U4.40 (DQ22)
/MEM_DQ23: U1.112 (IO/VREFB7N0/High_Speed), U4.42 (DQ23)
/MEM_DQ24: U1.91 (IO/CLK3n/DIFFIO_RX_R20n/DIFFOUT_R20n/Hi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), U4.45 (DQ24)
/MEM_DQ25: U1.90 (IO/CLK3p/DIFFIO_RX_R20p/DIFFOUT_R20p/Hi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), U4.47 (DQ25)
/MEM_DQ26: U1.89 (IO/CLK2n/DIFFIO_RX_R18n/DIFFOUT_R18n/Hi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), U4.48 (DQ26)
/MEM_DQ27: U1.88 (IO/CLK2p/DIFFIO_RX_R18p/DIFFOUT_R18p/Hi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), U4.50 (DQ27)
/MEM_DQ28: U1.87 (IO/DIFFIO_RX_R14n/DIFFOUT_R14n/High_Spe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), U4.51 (DQ28)
/MEM_DQ29: U1.86 (IO/DIFFIO_RX_R15n/DIFFOUT_R15n/High_Spe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), U4.53 (DQ29)
/MEM_DQ30: U1.85 (IO/DIFFIO_RX_R14p/DIFFOUT_R14p/High_Spe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), U4.54 (DQ30)
/MEM_DQ31: U1.84 (IO/DIFFIO_RX_R15p/DIFFOUT_R15p/High_Spe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), U4.56 (DQ31)
/MEM_DQM0: U1.44 (IO/DIFFIO_TX_RX_B5n/DIFFOUT_B5n/High_Sp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), U4.16 (DQM0)
/MEM_DQM1: U1.65 (IO/DIFFIO_TX_RX_B35p/DIFFOUT_B35p/High_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), U4.71 (DQM1)
/MEM_DQM2: U1.99 (IO/DIFFIO_RX_R31p/DIFFOUT_R31p/High_Spe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), U4.28 (DQM2)
/MEM_DQM3: U1.81 (IO/DIFFIO_RX_R11n/DIFFOUT_R11n/High_Spe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), U4.59 (DQM3)
/MEM_RASn: U1.47 (IO/DIFFIO_TX_RX_B13p/DIFFOUT_B13p/High_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), U4.19 (RASn)
/MEM_WEn: U1.45 (IO/DIFFIO_TX_RX_B5p/DIFFOUT_B5p/High_Sp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), U4.17 (WEn)
/PRI_CLK: U1.26 (IO/CLK0n/DIFFIO_RX_L20n/DIFFOUT_L20n/Hi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), U5.3 (OUT)
/PRI_CONFDONE: R14.2, R42.2, U1.138 (IO/CONF_DONE/DIFFIO_RX_T36n/DIFFOUT_T36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)
/PRI_CONFSEL: P2.1, R18.2, U1.126 (IO/CONFIG_SEL/Low_Speed)
/PRI_CRCERR: R17.2, U1.134 (IO/CRC_ERROR/DIFFIO_RX_T34n/DIFFOUT_T34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)
/PRI_DBG0: P2.2, U1.17 (IO/VREFB1N0/Low_Speed)
/PRI_DBG1: P2.4, U1.27 (IO/CLK0p/DIFFIO_RX_L20p/DIFFOUT_L20p/Hi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)
/PRI_DBG2: P2.6, U1.113 (IO)
/PRI_DBG3: P2.8, U1.22 (IO/DIFFIO_RX_L14p/DIFFOUT_L14p/Low_Speed)
/PRI_DBG4: P2.10, U1.54 (IO)
/PRI_DBG5: P2.9, U1.114 (IO)
/PRI_DBGRX: P2.5, U1.118 (IO/DIFFIO_RX_T22p/DIFFOUT_T22p/High_Spe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)
/PRI_DBGTX: P2.7, U1.66 (IO)
/PRI_DEVCLRN: R20.1, U1.121 (IO/DEV_CLRn/DIFFIO_RX_T28n/DIFFOUT_T28n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)
/PRI_DEVOE: R21.1, U1.122 (IO/DEV_OE)
/PRI_FDBG: P2.3, U1.21 (IO/DIFFIO_RX_L14n/DIFFOUT_L14n/Low_Speed)
/PRI_FHLT: R15.2, U1.62 (IO)
/PRI_INT: R9.1, SW2.2, U1.24 (IO/DIFFIO_RX_L16n/DIFFOUT_L16n/Low_Speed)
/PRI_NCONFIG: R22.1, SW4.2, U1.129 (Input_only/nCONFIG/Low_Speed)
/PRI_NSTATUS: R16.2, U1.136 (IO/nSTATUS/DIFFIO_RX_T36p/DIFFOUT_T36p/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)
/PRI_RST: R10.1, SW3.2, U1.25 (IO/DIFFIO_RX_L16p/DIFFOUT_L16p/Low_Speed)
/PS2_CLK: P10.5, R39.2, U3.141 (IO/DIFFIO_RX_T38n/DIFFOUT_T38n/Low_Speed)
/PS2_DAT: P10.1, R36.2, U3.140 (IO/DIFFIO_RX_T38p/DIFFOUT_T38p/Low_Speed)
/SER_CTS: U3.78 (IO/High_Speed), U8.16 (R_OUT)
/SER_DCD: U3.76 (IO/DIFFIO_RX_R2n/DIFFOUT_R2n/High_Speed), U8.17 (R_OUT)
/SER_DSR: U3.69 (IO/DIFFIO_TX_RX_B41n/DIFFOUT_B41n/High_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), U8.18 (R_OUT)
/SER_DTR: U3.85 (IO/DIFFIO_RX_R14p/DIFFOUT_R14p/High_Spe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), U8.12 (T_IN)
/SER_RTS: U3.81 (IO/DIFFIO_RX_R11n/DIFFOUT_R11n/High_Spe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), U8.13 (T_IN)
/SER_RX: U3.79 (IO/DIFFIO_RX_R11p/DIFFOUT_R11p/High_Spe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), U8.15 (R_OUT)
/SER_TX: U3.80 (IO/VREFB5N0/High_Speed), U8.14 (T_IN)
/SPI_CD0: CON3.10 (CARD_DETECT), U3.55 (IO/CLK6n/DIFFIO_TX_RX_B18n/DIFFOUT_B18n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)
/SPI_CD1: CON4.10 (CARD_DETECT), U3.56 (IO/CLK6p/DIFFIO_TX_RX_B18p/DIFFOUT_B18p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)
/SPI_MISO: CON3.7 (DAT0), CON4.7 (DAT0), P4.7, R60.2, R61.2, U3.43 (IO/DIFFIO_TX_RX_B3p/DIFFOUT_B3p/High_Sp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)
/SPI_MOSI: CON3.2 (CMD), CON4.2 (CMD), P4.8, R54.2, R55.2, U3.44 (IO/DIFFIO_TX_RX_B5n/DIFFOUT_B5n/High_Sp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)
/SPI_SCLK: CON3.5 (CLK), CON4.5 (CLK), P4.4, R57.2, R58.2, U3.60 (IO/DIFFIO_TX_RX_B22p/DIFFOUT_B22p/High_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)
/SPI_SS0: P4.5, U3.45 (IO/DIFFIO_TX_RX_B5p/DIFFOUT_B5p/High_Sp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)
/SPI_SS1: CON3.1 (CD/DAT3), R51.2, U3.48 (IO/VREFB3N0/High_Speed)
/SPI_SS2: CON4.1 (CD/DAT3), R52.2, U3.59 (IO/DIFFIO_TX_RX_B22n/DIFFOUT_B22n/High_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)
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

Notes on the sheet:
What're these for?

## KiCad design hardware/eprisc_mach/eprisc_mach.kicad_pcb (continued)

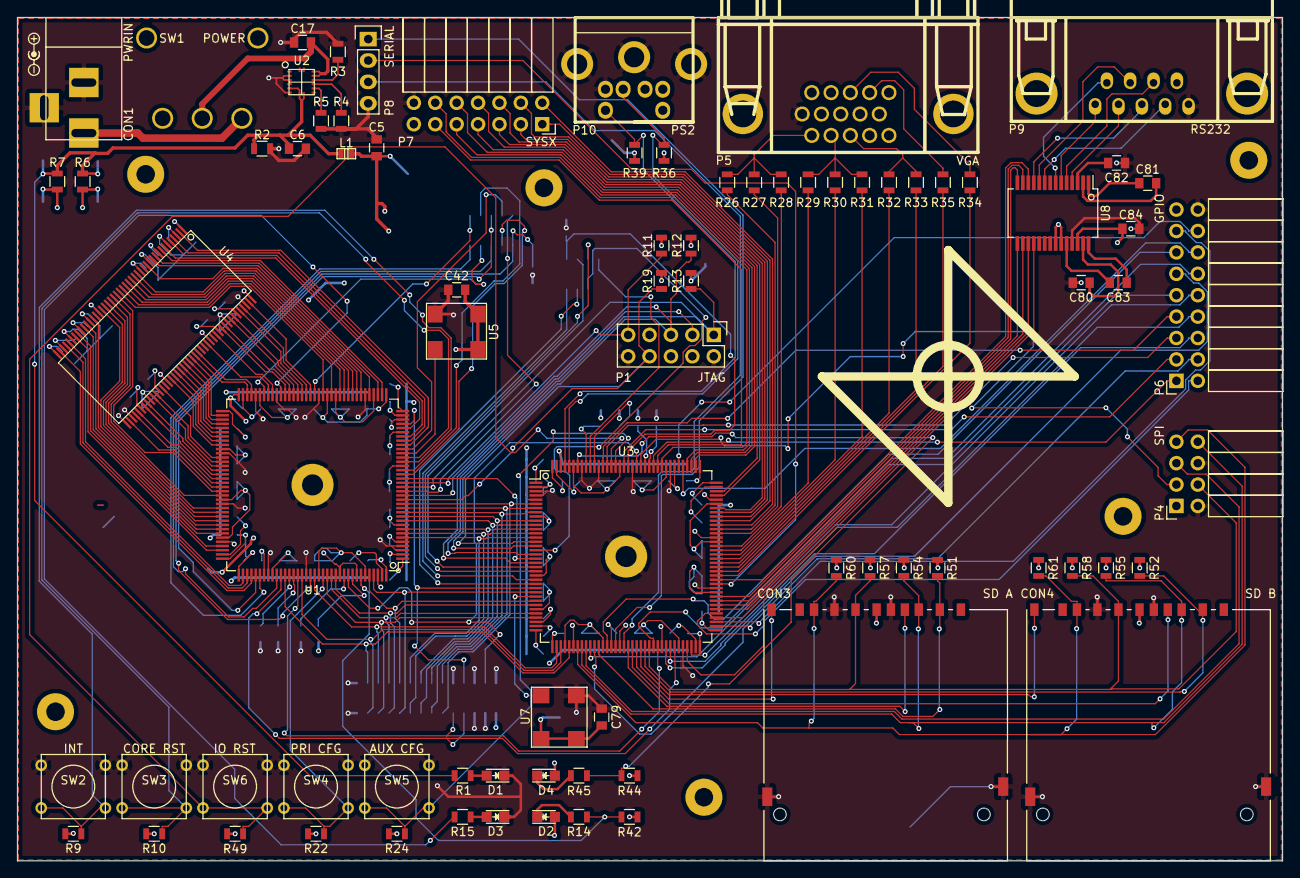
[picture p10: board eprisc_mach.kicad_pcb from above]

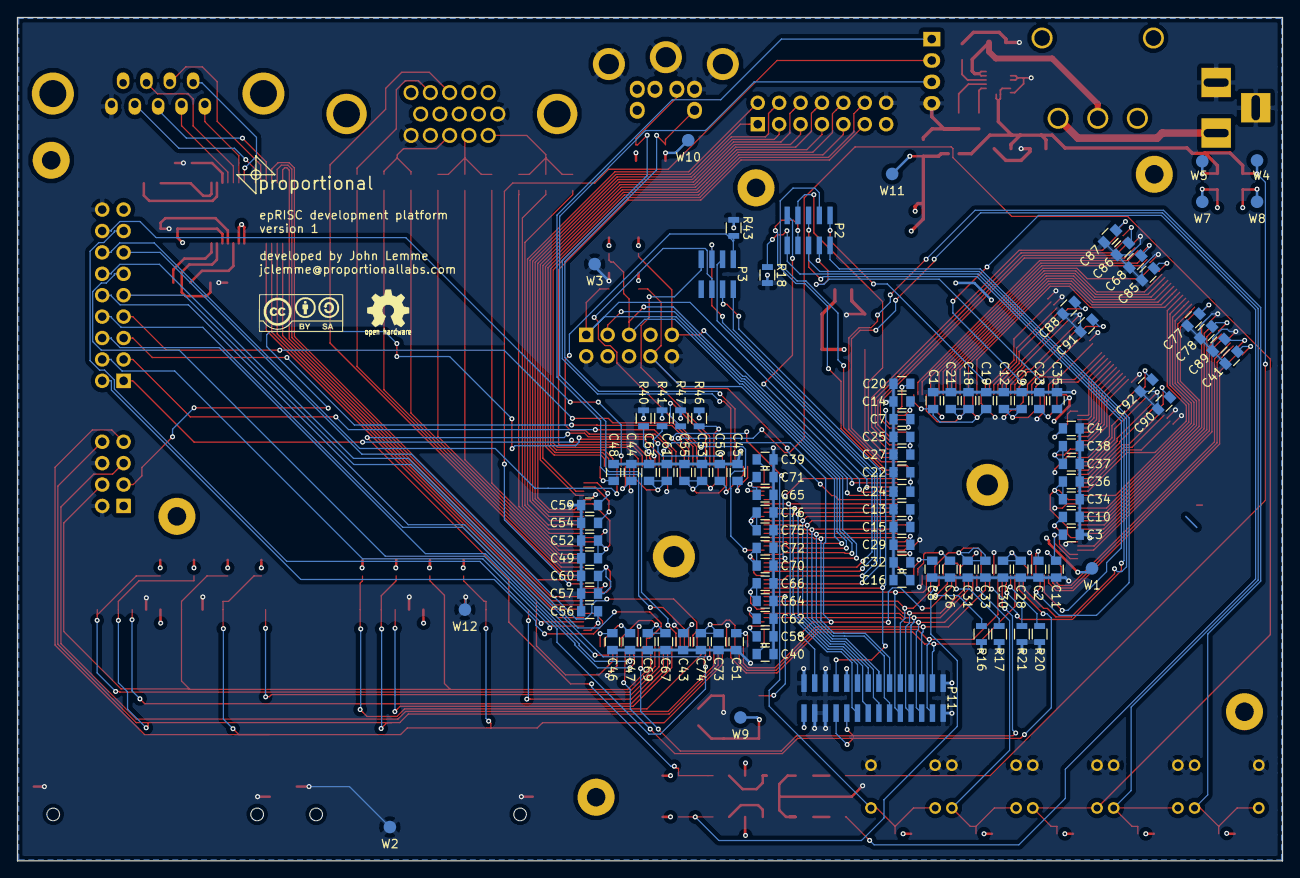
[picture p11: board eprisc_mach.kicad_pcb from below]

Board: 4 copper layers, 150.1 x 100.1 mm, 190 parts (107 on the bottom side), 210 nets.

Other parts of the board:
LOGO: logogood
LOGO_TINY: logotiny

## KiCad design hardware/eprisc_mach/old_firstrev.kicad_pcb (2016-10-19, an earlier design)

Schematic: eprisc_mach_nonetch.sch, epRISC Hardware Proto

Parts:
C1, C2, C3, C4, C7, C8, C9, C10, C11, C13, C14, C16, C18, C19, C20, C22, C23, C25, C26, C28, C29, C31, C32, C34, C35, C37, C40, C42, C43, C44, C45, C46, C47, C48, C49, C50, C51, C53, C54, C56, C57, C58, C59, C61, C62, C64, C65, C67, C68, C70, C71, C73, C75, C78, C79, C80, C81, C82, C83, C84: 0.1u; C_0805
C5: 10u; C_0805
C6: 47u/16v; C_0805
C12, C15, C21, C24, C27, C30, C33, C36, C38, C39, C41, C52, C55, C60, C63, C66, C69, C72, C74, C76, C77: 1u; C_0805
C17: 4.7u; C_0805
CON1: POWER_IN_5V; BARREL_JACK
CON2: SD_INT; microsd_socket
CON3: SD_A; SD_Card_Receptacle
CON4: SD_B; SD_Card_Receptacle
D1: GREEN; LED_0805
D2, D4: CONF_DONE; LED_0805
D3: HALT; LED_0805
L1: 600o/500mA; inductor_smd_4.8x2.8mm
L2, L3: FERRITE_BEAD; inductor_smd_0805
P1: PRI_PROG; Pin_Header_Straight_2x05
P2: PRI_DBG; Pin_Header_Straight_2x05
P3: AUX_DBG; Pin_Header_Straight_2x04
P4: AUX_PROG; Pin_Header_Straight_2x05
P5: VGA; DB_15F-VGA
P6: GPIO; Socket_Strip_Angled_2x09
P7: SYSX_EXT; Socket_Strip_Angled_2x07
P8: TTL_SERIAL; Socket_Strip_Straight_1x04
P9: RS232; DB_9F
P10: PS2; minidin-8
P11: SYSX_INT; bb080_28
R1, R13, R14, R15, R16, R17, R27, R30, R32, R38, R45, R46, R47: 1K; R_0805
R2: DNI; R_0805
R3, R4, R5, R8, R20, R21, R23, R40, R41: 0; R_0805
R6, R7: 0.1; R_0805
R9, R10, R42, R44: 3.3K; R_0805
R11, R12, R18, R19, R22, R24, R25, R36, R37, R39, R43, R48, R49: 10K; R_0805
R26, R29: 2K; R_0805
R28, R31, R33: 510; R_0805
R34, R35: 100; R_0805
R50, R51, R52, R53, R54, R55, R56, R57, R58, R59, R60, R61: 50K; R_0805
SW1: POWER; SW_SPDT
SW2: CORE_INT; smd_push2
SW3: CORE_RST; smd_push2
SW4: PRI_CONFIG; smd_push2
SW5: AUX_CONFIG; smd_push2
SW6: IO_RST; smd_push2
U1, U6: MAX10-10M16SA-E144; LQFP-144_20x20mm_Pitch0.5mm
U2: EP5388QI; QFN-16-ALTERA
U3: MCP1525; SOT-23
U4: IS45S32800J; TSOP-86
U5, U7: CB3LV-3C-50M0000; CRYSTAL_CTS
U8: MAX3244; SSOP-28_5.3x10.2mm_Pitch0.65mm
W1, W4, W5, W7, W8: TEST_1P; Measurement_Point_Round-SMD-Pad_Small
W2, W3, W6, W12: GND; Measurement_Point_Round-SMD-Pad_Small
W9: V_CORE; Measurement_Point_Round-SMD-Pad_Small
W10: V_IO; Measurement_Point_Round-SMD-Pad_Small
W11: V_VCCIO; Measurement_Point_Round-SMD-Pad_Small
W13: GNDA; Measurement_Point_Round-SMD-Pad_Small
W14: V_REF; Measurement_Point_Round-SMD-Pad_Small

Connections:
+2V5: C39.1, C41.1, C77.1, U1.5, U3.2, U6.5, W14.1
+3V3: C6.1, L1.1, R1.2, R2.1, R6.1, R7.1, U2.5 (VSENSE), U2.7 (VOUT), U2.8 (VOUT), W4.1, W5.1
+5V: C17.1, P10.4, SW1.2, U2.13 (ENABLE), U2.14 (VIN)
/AUX_CLK: U6.28, U7.3 (OUT)
/AUX_CONFDONE: R44.2, R45.2, U6.138
/AUX_CONFSEL: P3.1, R43.2, U6.126
/AUX_CRCERR: R47.2, U6.134
/AUX_DBG0: P3.3, U6.21
/AUX_DBG1: P3.5, U6.22
/AUX_DBG2: P3.2, U6.24
/AUX_DBG3: P3.4, U6.25
/AUX_DBG4: P3.6, U6.17
/AUX_DBG5: P3.7, U6.135
/AUX_DBG6: P3.8, U6.123
/AUX_DEVCLRN: R40.1, U6.121
/AUX_DEVOE: R41.1, U6.122
/AUX_JTAGEN: P4.8, R48.1, U6.15
/AUX_NCONFIG: R24.1, SW5.2, U6.129
/AUX_NSTATUS: R46.2, U6.136
/AUX_RST: R49.1, SW6.2, U6.130
/AUX_TCK: P4.1, R38.2, U6.18
/AUX_TDI: P4.9, R25.1, U6.19
/AUX_TDO: P4.3, U6.20
/AUX_TMS: P4.5, R37.1, U6.16
/BUS_CLK: P11.21, U1.33, U6.26
/BUS_INT: P11.25, U1.135, U6.124
/BUS_MISO0: P11.3, U1.141, U6.65
/BUS_MISO1: P11.15, U1.140, U6.69
/BUS_MISO2: P11.11, U1.130, U6.27
/BUS_MISO3: P11.13, U1.131, U6.29
/BUS_MISO4: P11.9, U1.132, U6.32
/BUS_MISO5: P11.7, U1.127, U6.33
/BUS_MISO6: P11.5, U1.124, U6.30
/BUS_MISO7: P11.17, U1.120, U6.64
/BUS_MOSI0: P11.4, U1.6, U6.6
/BUS_MOSI1: P11.6, U1.7, U6.7
/BUS_MOSI2: P11.8, U1.8, U6.8
/BUS_MOSI3: P11.10, U1.10, U6.10
/BUS_MOSI4: P11.12, U1.11, U6.11
/BUS_MOSI5: P11.14, U1.12, U6.12
/BUS_MOSI6: P11.16, U1.13, U6.13
/BUS_MOSI7: P11.18, U1.14, U6.14
/BUS_SS0: P11.20, U1.123, U6.62
/BUS_SS1: P11.22, U1.111, U6.66
/EXB_CLK: P7.12, U6.84
/EXB_INT: P7.11, U6.80
/EXB_MISO0: P7.1, U6.75
/EXB_MISO1: P7.3, U6.77
/EXB_MISO2: P7.5, U6.74
/EXB_MISO3: P7.7, U6.76
/EXB_MOSI0: P7.2, U6.79
/EXB_MOSI1: P7.4, U6.81
/EXB_MOSI2: P7.6, U6.85
/EXB_MOSI3: P7.8, U6.87
/EXB_SS0: P7.9, U6.86
/EXB_SS1: P7.10, U6.78
/GIO_PIN0: P6.1, U6.99
/GIO_PIN1: P6.3, U6.101
/GIO_PIN2: P6.5, U6.100
/GIO_PIN3: P6.7, U6.102
/GIO_PIN4: P6.9, U6.105
/GIO_PIN5: P6.11, U6.106
/GIO_PIN6: P6.13, U6.97
/GIO_PIN7: P6.15, U6.110
/GIO_PIN8: P6.2, U6.111
/GIO_PIN9: P6.4, U6.118
/GIO_PIN10: P6.6, U6.119
/GIO_PIN11: P6.8, U6.112
/GIO_PIN12: P6.10, U6.70
/GIO_PIN13: P6.12, U6.61
/GIO_PIN14: P6.14, U6.113
/GIO_PIN15: P6.16, U6.114
/MEM_A0: U1.61, U4.25 (A0)
/MEM_A1: U1.65, U4.26 (A1)
/MEM_A2: U1.64, U4.27 (A2)
/MEM_A3: U1.96, U4.60 (A3)
/MEM_A4: U1.93, U4.61 (A4)
/MEM_A5: U1.92, U4.62 (A5)
/MEM_A6: U1.91, U4.63 (A6)
/MEM_A7: U1.90, U4.64 (A7)
/MEM_A8: U1.89, U4.65 (A8)
/MEM_A9: U1.88, U4.66 (A9)
/MEM_A10: U1.44, U4.24 (A10)
/MEM_A11: U1.45, U4.21 (A11)
/MEM_BA0: U1.43, U4.22 (BA0)
/MEM_BA1: U1.41, U4.23 (BA1)
/MEM_CASn: U1.119, U4.18 (CASn)
/MEM_CKE: U1.110, U4.67 (CKE)
/MEM_CLK: U1.32, U4.68 (CLK)
/MEM_CSn: U1.114, U4.20 (CSn)
/MEM_DQ0: U1.55, U4.2 (DQ0)
/MEM_DQ1: U1.56, U4.4 (DQ1)
/MEM_DQ2: U1.57, U4.5 (DQ2)
/MEM_DQ3: U1.58, U4.7 (DQ3)
/MEM_DQ4: U1.46, U4.8 (DQ4)
/MEM_DQ5: U1.47, U4.10 (DQ5)
/MEM_DQ6: U1.50, U4.11 (DQ6)
/MEM_DQ7: U1.52, U4.13 (DQ7)
/MEM_DQ8: U1.60, U4.74 (DQ8)
/MEM_DQ9: U1.87, U4.76 (DQ9)
/MEM_DQ10: U1.86, U4.77 (DQ10)
/MEM_DQ11: U1.48, U4.79 (DQ11)
/MEM_DQ12: U1.85, U4.80 (DQ12)
/MEM_DQ13: U1.84, U4.82 (DQ13)
/MEM_DQ14: U1.81, U4.83 (DQ14)
/MEM_DQ15: U1.80, U4.85 (DQ15)
/MEM_DQ16: U1.69, U4.31 (DQ16)
/MEM_DQ17: U1.70, U4.33 (DQ17)
/MEM_DQ18: U1.74, U4.34 (DQ18)
/MEM_DQ19: U1.75, U4.36 (DQ19)
/MEM_DQ20: U1.76, U4.37 (DQ20)
/MEM_DQ21: U1.77, U4.39 (DQ21)
/MEM_DQ22: U1.78, U4.40 (DQ22)
/MEM_DQ23: U1.79, U4.42 (DQ23)
/MEM_DQ24: U1.106, U4.45 (DQ24)
/MEM_DQ25: U1.105, U4.47 (DQ25)
/MEM_DQ26: U1.102, U4.48 (DQ26)
/MEM_DQ27: U1.101, U4.50 (DQ27)
/MEM_DQ28: U1.100, U4.51 (DQ28)
/MEM_DQ29: U1.99, U4.53 (DQ29)
/MEM_DQ30: U1.98, U4.54 (DQ30)
/MEM_DQ31: U1.97, U4.56 (DQ31)
/MEM_DQM0: U1.21, U4.16 (DQM0)
/MEM_DQM1: U1.22, U4.71 (DQM1)
/MEM_DQM2: U1.24, U4.28 (DQM2)
/MEM_DQM3: U1.25, U4.59 (DQM3)
/MEM_RASn: U1.112, U4.19 (RASn)
/MEM_WEn: U1.118, U4.17 (WEn)
/PRI_CLK: U1.26, U5.3 (OUT)
/PRI_CONFDONE: R14.2, R42.2, U1.138
/PRI_CONFSEL: P2.1, R18.2, U1.126
/PRI_CRCERR: R17.2, U1.134
/PRI_DBG0: P2.2, U1.17
/PRI_DBG1: P2.4, U1.27
/PRI_DBG2: P2.6, U1.39
/PRI_DBG3: P2.8, U1.59
/PRI_DBG4: P2.10, U1.54
/PRI_DBG5: P2.9, U1.113
/PRI_DBGRX: P2.5, U1.38
/PRI_DBGTX: P2.7, U1.66
/PRI_DEVCLRN: R20.1, U1.121
/PRI_DEVOE: R21.1, U1.122
/PRI_FDBG: P2.3, U1.30
/PRI_FHLT: R15.2, U1.62
/PRI_INT: R9.1, SW2.2, U1.28
/PRI_JTAGEN: P1.8, R19.1, U1.15
/PRI_NCONFIG: R22.1, SW4.2, U1.129
/PRI_NSTATUS: R16.2, U1.136
/PRI_RST: R10.1, SW3.2, U1.29
/PRI_TCK: P1.1, R13.2, U1.18
/PRI_TDI: P1.9, R11.1, U1.19
/PRI_TDO: P1.3, U1.20
/PRI_TMS: P1.5, R12.1, U1.16
/PS2_CLK: P10.5, R39.2, U6.141
/PS2_DAT: P10.1, R36.2, U6.140
/SER_CTS: U6.45, U8.16 (R_OUT)
/SER_DCD: U6.48, U8.17 (R_OUT)
/SER_DSR: U6.43, U8.18 (R_OUT)
/SER_DTR: U6.41, U8.12 (T_IN)
/SER_RTS: U6.44, U8.13 (T_IN)
/SER_RX: U6.59, U8.15 (R_OUT)
/SER_TX: U6.60, U8.14 (T_IN)
/SPI_CD0: CON3.10 (CARD_DETECT), U6.131
/SPI_CD1: CON4.10 (CARD_DETECT), U6.132
/SPI_MISO: CON2.7, CON3.7 (DAT0), CON4.7 (DAT0), R59.2, R60.2, R61.2, U6.90
/SPI_MOSI: CON2.3, CON3.2 (CMD), CON4.2 (CMD), R53.2, R54.2, R55.2, U6.91
/SPI_SCLK: CON2.5, CON3.5 (CLK), CON4.5 (CLK), R56.2, R57.2, R58.2, U6.98
/SPI_SS0: CON2.2, R50.2, U6.92
/SPI_SS1: CON3.1 (CD/DAT3), R51.2, U6.93
/SPI_SS2: CON4.1 (CD/DAT3), R52.2, U6.96
/SPI_WP0: CON3.11 (WRITE_PROTECT), U6.120
/SPI_WP1: CON4.11 (WRITE_PROTECT), U6.127
/TTL_RTS: P8.3, U6.54
/TTL_RX: P8.1, U6.88
/TTL_TX: P8.2, U6.89
/VGA_B0: R32.2, U6.50
/VGA_B1: R33.2, U6.52
/VGA_G0: R29.2, U6.58
/VGA_G1: R30.2, U6.46
/VGA_G2: R31.2, U6.47
/VGA_HS: R34.2, U6.38
/VGA_R0: R26.2, U6.55
/VGA_R1: R27.2, U6.56
/VGA_R2: R28.2, U6.57
/VGA_VS: R35.2, U6.39
unnamed: C40.1, R8.1, U1.3
unnamed: C78.1, R23.1, U6.3
unnamed: C80.1, U8.27 (V+)
unnamed: C81.1, U8.1 (C2+)
unnamed: C81.2, U8.2 (C2-)
unnamed: C82.2, U8.3 (V-)
unnamed: C83.1, U8.28 (C1+)
unnamed: C83.2, U8.24 (C1-)
unnamed: CON1.1, SW1.1
unnamed: D1.2 (A), R1.1
unnamed: D2.2 (A), R14.1
unnamed: D3.2 (A), R15.1
unnamed: D4.2 (A), R45.1
unnamed: L2.1, U1.4
unnamed: L3.1, U6.4
unnamed: P5.1, R26.1, R27.1, R28.1
unnamed: P5.2, R29.1, R30.1, R31.1
unnamed: P5.3, R32.1, R33.1
unnamed: P5.13, R34.1
unnamed: P5.14, R35.1
unnamed: P9.1, U8.6 (R_IN)
unnamed: P9.2, U8.4 (R_IN)
unnamed: P9.3, U8.11 (T_OUT)
unnamed: P9.4, U8.9 (T_OUT)
unnamed: P9.6, U8.7 (R_IN)
unnamed: P9.7, U8.10 (T_OUT)
unnamed: P9.8, U8.5 (R_IN)
unnamed: R3.1, U2.12 (VS2)
unnamed: R4.1, U2.11 (VS1)
unnamed: R5.1, U2.10 (VS0)
VAA: C9.1, C12.1, C13.1, C15.1, C18.1, C21.1, C22.1, C24.1, C25.1, C27.1, C28.1, C30.1, C31.1, C33.1, C34.1, C36.1, C37.1, C38.1, C49.1, C52.1, C53.1, C55.1, C57.1, C60.1, C61.1, C63.1, C64.1, C66.1, C67.1, C69.1, C70.1, C72.1, C73.1, C74.1, C75.1, C76.1, C84.1, CON2.4, CON3.4 (VDD), CON4.4 (VDD), P1.4, P4.4, P6.17, P7.13, P11.28, R7.2, R9.2, R10.2, R11.2, R12.2, R16.1, R17.1, R19.2, R22.2, R24.2, R25.2, R36.1, R37.2, R39.1, R42.1, R44.1, R46.1, R47.1, R48.2, R49.2, R50.1, R51.1, R52.1, R53.1, R54.1, R55.1, R56.1, R57.1, R58.1, R59.1, R60.1, R61.1, U1.9, U1.23, U1.31, U1.40, U1.49, U1.67, U1.82, U1.94, U1.103, U1.117, U1.128, U1.139, U4.3 (VDDq), U4.9 (VDDq), U4.35 (VDDq), U4.41 (VDDq), U4.49 (VDDq), U4.55 (VDDq), U4.75 (VDDq), U4.81 (VDDq), U6.9, U6.23, U6.31, U6.40, U6.49, U6.67, U6.82, U6.94, U6.103, U6.117, U6.128, U6.139, U8.22 (FORCEOFFn), U8.23 (FORCEON), U8.26 (VCC), W8.1, W10.1
VCC: C1.1, C2.1, C3.1, C4.1, C7.1, C10.1, C14.1, C19.1, C23.1, C26.1, C29.1, C32.1, C42.2, C43.1, C44.1, C45.1, C46.1, C47.1, C50.1, C54.1, C58.1, C62.1, C65.1, C68.1, C71.1, C79.2, R6.2, U1.2, U1.34, U1.35, U1.71, U1.107, U1.143, U4.1 (VDD), U4.15 (VDD), U4.29 (VDD), U4.43 (VDD), U5.1 (EN), U5.4 (VCC), U6.2, U6.34, U6.35, U6.71, U6.107, U6.143, U7.1 (EN), U7.4 (VCC), W7.1, W9.1
VEE: C5.1, C8.1, C11.1, C16.1, C20.1, C35.1, C48.1, C51.1, C56.1, C59.1, L1.2, U1.1, U1.36, U1.37, U1.51, U1.72, U1.73, U1.108, U1.109, U1.115, U1.144, U3.1, U6.1, U6.36, U6.37, U6.51, U6.72, U6.73, U6.108, U6.109, U6.115, U6.144, W1.1, W11.1

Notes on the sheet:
What're these for?

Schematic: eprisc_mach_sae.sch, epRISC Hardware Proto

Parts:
C1, C2, C3, C4, C7, C8, C9, C10, C11, C13, C14, C16, C18, C19, C20, C22, C23, C25, C26, C28, C29, C31, C32, C34, C35, C37, C40, C42, C43, C44, C45, C46, C47, C48, C49, C50, C51, C53, C54, C56, C57, C58, C59, C61, C62, C64, C65, C67, C68, C70, C71, C73, C75, C78, C79, C80, C81, C82, C83, C84: 0.1u; C_0805
C5: 10u; C_0805
C6: 47u/16v; C_0805
C12, C15, C21, C24, C27, C30, C33, C36, C38, C39, C41, C52, C55, C60, C63, C66, C69, C72, C74, C76, C77: 1u; C_0805
C17: 4.7u; C_0805
CON1: POWER_IN_5V; BARREL_JACK
CON2: SD_INT; microsd_socket
CON3: SD_A; SD_Card_Receptacle
CON4: SD_B; SD_Card_Receptacle
D1: GREEN; LED_0805
D2, D4: CONF_DONE; LED_0805
D3: HALT; LED_0805
L1: 600o/500mA; inductor_smd_0603
L2, L3: FERRITE_BEAD; inductor_smd_0402
P1: PRI_PROG; SMD_STRIP_10
P2: PRI_DBG; SMD_STRIP_10
P3: AUX_DBG; SMD_STRIP_8
P4: AUX_PROG; SMD_STRIP_10
P5: VGA; DB15F-VGA-AMP
P6: GPIO; Socket_Strip_Angled_2x09
P7: SYSX_EXT; Socket_Strip_Angled_2x07
P8: TTL_SERIAL; Socket_Strip_Straight_1x04
P9: RS232; DB_9F
P10: PS2; 00JG-MiniDin6
P11: SYSX_INT; SMD_STRIP_28
R1, R13, R14, R15, R16, R17, R27, R30, R32, R38, R45, R46, R47: 1K; R_0805
R2: DNI; R_0805
R3, R4, R5, R8, R20, R21, R23, R40, R41: 0; R_0805
R6, R7: 0.1; R_0805
R9, R10, R42, R44: 3.3K; R_0805
R11, R12, R18, R19, R22, R24, R25, R36, R37, R39, R43, R48, R49, R50, R51, R52, R53, R54, R55, R56, R57, R58, R59, R60, R61: 10K; R_0805
R26, R29: 2K; R_0805
R28, R31, R33: 510; R_0805
R34, R35: 100; R_0805
SW1: POWER; SW_SLIDE_PWR
SW2: CORE_INT; smd_push2
SW3: CORE_RST; smd_push2
SW4: PRI_CONFIG; smd_push2
SW5: AUX_CONFIG; smd_push2
SW6: IO_RST; smd_push2
U1, U6: MAX10-10M16SA-E144; LQFP-144_20x20mm_Pitch0.5mm
U2: EP5388QI; QFN-16-ALTERA
U3: MCP1525; SOT-23
U4: IS45S32800J; TSOP-86
U5, U7: CB3LV-3C-50M0000; CRYSTAL_CTS
U8: MAX3244; SSOP-28_5.3x10.2mm_Pitch0.65mm
W1, W4, W5, W7, W8: TEST_1P; Measurement_Point_Round-SMD-Pad_Small
W2, W3, W6, W12: GND; Measurement_Point_Round-SMD-Pad_Small
W9: V_CORE; Measurement_Point_Round-SMD-Pad_Small
W10: V_IO; Measurement_Point_Round-SMD-Pad_Small
W11: V_VCCIO; Measurement_Point_Round-SMD-Pad_Small
W13: GNDA; Measurement_Point_Round-SMD-Pad_Small
W14: V_REF; Measurement_Point_Round-SMD-Pad_Small

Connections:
+2V5: C39.1, C41.1, C77.1, U1.5, U3.2, U6.5, W14.1
+3V3: C6.1, L1.1, R1.2, R2.1, R6.1, R7.1, U2.5 (VSENSE), U2.7 (VOUT), U2.8 (VOUT), W4.1, W5.1
+5V: C17.1, P10.4, SW1.2, U2.13 (ENABLE), U2.14 (VIN)
/AUX_CLK: U6.28, U7.3 (OUT)
/AUX_CONFDONE: R44.2, R45.2, U6.138
/AUX_CONFSEL: P3.1, R43.2, U6.126
/AUX_CRCERR: R47.2, U6.134
/AUX_DBG0: P3.3, U6.21
/AUX_DBG1: P3.5, U6.22
/AUX_DBG2: P3.2, U6.24
/AUX_DBG3: P3.4, U6.25
/AUX_DBG4: P3.6, U6.17
/AUX_DBG5: P3.7, U6.135
/AUX_DBG6: P3.8, U6.123
/AUX_DEVCLRN: R40.1, U6.121
/AUX_DEVOE: R41.1, U6.122
/AUX_JTAGEN: P4.8, R48.1, U6.15
/AUX_NCONFIG: R24.1, SW5.2, U6.129
/AUX_NSTATUS: R46.2, U6.136
/AUX_RST: R49.1, SW6.2, U6.130
/AUX_TCK: P4.1, R38.2, U6.18
/AUX_TDI: P4.9, R25.1, U6.19
/AUX_TDO: P4.3, U6.20
/AUX_TMS: P4.5, R37.1, U6.16
/BUS_CLK: P11.21, U1.33, U6.26
/BUS_INT: P11.25, U1.135, U6.124
/BUS_MISO0: P11.3, U1.141, U6.65
/BUS_MISO1: P11.15, U1.140, U6.69
/BUS_MISO2: P11.11, U1.130, U6.27
/BUS_MISO3: P11.13, U1.131, U6.29
/BUS_MISO4: P11.9, U1.132, U6.32
/BUS_MISO5: P11.7, U1.127, U6.33
/BUS_MISO6: P11.5, U1.124, U6.30
/BUS_MISO7: P11.17, U1.120, U6.64
/BUS_MOSI0: P11.4, U1.6, U6.6
/BUS_MOSI1: P11.6, U1.7, U6.7
/BUS_MOSI2: P11.8, U1.8, U6.8
/BUS_MOSI3: P11.10, U1.10, U6.10
/BUS_MOSI4: P11.12, U1.11, U6.11
/BUS_MOSI5: P11.14, U1.12, U6.12
/BUS_MOSI6: P11.16, U1.13, U6.13
/BUS_MOSI7: P11.18, U1.14, U6.14
/BUS_SS0: P11.20, U1.123, U6.62
/BUS_SS1: P11.22, U1.111, U6.66
/EXB_CLK: P7.12, U6.84
/EXB_INT: P7.11, U6.80
/EXB_MISO0: P7.1, U6.75
/EXB_MISO1: P7.3, U6.77
/EXB_MISO2: P7.5, U6.74
/EXB_MISO3: P7.7, U6.76
/EXB_MOSI0: P7.2, U6.79
/EXB_MOSI1: P7.4, U6.81
/EXB_MOSI2: P7.6, U6.85
/EXB_MOSI3: P7.8, U6.87
/EXB_SS0: P7.9, U6.86
/EXB_SS1: P7.10, U6.78
/GIO_PIN0: P6.1, U6.99
/GIO_PIN1: P6.3, U6.101
/GIO_PIN2: P6.5, U6.100
/GIO_PIN3: P6.7, U6.102
/GIO_PIN4: P6.9, U6.105
/GIO_PIN5: P6.11, U6.106
/GIO_PIN6: P6.13, U6.97
/GIO_PIN7: P6.15, U6.110
/GIO_PIN8: P6.2, U6.111
/GIO_PIN9: P6.4, U6.118
/GIO_PIN10: P6.6, U6.119
/GIO_PIN11: P6.8, U6.112
/GIO_PIN12: P6.10, U6.70
/GIO_PIN13: P6.12, U6.61
/GIO_PIN14: P6.14, U6.113
/GIO_PIN15: P6.16, U6.114
/MEM_A0: U1.61, U4.25 (A0)
/MEM_A1: U1.65, U4.26 (A1)
/MEM_A2: U1.64, U4.27 (A2)
/MEM_A3: U1.96, U4.60 (A3)
/MEM_A4: U1.93, U4.61 (A4)
/MEM_A5: U1.92, U4.62 (A5)
/MEM_A6: U1.91, U4.63 (A6)
/MEM_A7: U1.90, U4.64 (A7)
/MEM_A8: U1.89, U4.65 (A8)
/MEM_A9: U1.88, U4.66 (A9)
/MEM_A10: U1.44, U4.24 (A10)
/MEM_A11: U1.45, U4.21 (A11)
/MEM_BA0: U1.43, U4.22 (BA0)
/MEM_BA1: U1.41, U4.23 (BA1)
/MEM_CASn: U1.119, U4.18 (CASn)
/MEM_CKE: U1.110, U4.67 (CKE)
/MEM_CLK: U1.32, U4.68 (CLK)
/MEM_CSn: U1.114, U4.20 (CSn)
/MEM_DQ0: U1.55, U4.2 (DQ0)
/MEM_DQ1: U1.56, U4.4 (DQ1)
/MEM_DQ2: U1.57, U4.5 (DQ2)
/MEM_DQ3: U1.58, U4.7 (DQ3)
/MEM_DQ4: U1.46, U4.8 (DQ4)
/MEM_DQ5: U1.47, U4.10 (DQ5)
/MEM_DQ6: U1.50, U4.11 (DQ6)
/MEM_DQ7: U1.52, U4.13 (DQ7)
/MEM_DQ8: U1.60, U4.74 (DQ8)
/MEM_DQ9: U1.87, U4.76 (DQ9)
/MEM_DQ10: U1.86, U4.77 (DQ10)
/MEM_DQ11: U1.48, U4.79 (DQ11)
/MEM_DQ12: U1.85, U4.80 (DQ12)
/MEM_DQ13: U1.84, U4.82 (DQ13)
/MEM_DQ14: U1.81, U4.83 (DQ14)
/MEM_DQ15: U1.80, U4.85 (DQ15)
/MEM_DQ16: U1.69, U4.31 (DQ16)
/MEM_DQ17: U1.70, U4.33 (DQ17)
/MEM_DQ18: U1.74, U4.34 (DQ18)
/MEM_DQ19: U1.75, U4.36 (DQ19)
/MEM_DQ20: U1.76, U4.37 (DQ20)
/MEM_DQ21: U1.77, U4.39 (DQ21)
/MEM_DQ22: U1.78, U4.40 (DQ22)
/MEM_DQ23: U1.79, U4.42 (DQ23)
/MEM_DQ24: U1.106, U4.45 (DQ24)
/MEM_DQ25: U1.105, U4.47 (DQ25)
/MEM_DQ26: U1.102, U4.48 (DQ26)
/MEM_DQ27: U1.101, U4.50 (DQ27)
/MEM_DQ28: U1.100, U4.51 (DQ28)
/MEM_DQ29: U1.99, U4.53 (DQ29)
/MEM_DQ30: U1.98, U4.54 (DQ30)
/MEM_DQ31: U1.97, U4.56 (DQ31)
/MEM_DQM0: U1.21, U4.16 (DQM0)
/MEM_DQM1: U1.22, U4.71 (DQM1)
/MEM_DQM2: U1.24, U4.28 (DQM2)
/MEM_DQM3: U1.25, U4.59 (DQM3)
/MEM_RASn: U1.112, U4.19 (RASn)
/MEM_WEn: U1.118, U4.17 (WEn)
/PRI_CLK: U1.26, U5.3 (OUT)
/PRI_CONFDONE: R14.2, R42.2, U1.138
/PRI_CONFSEL: P2.1, R18.2, U1.126
/PRI_CRCERR: R17.2, U1.134
/PRI_DBG0: P2.2, U1.17
/PRI_DBG1: P2.4, U1.27
/PRI_DBG2: P2.6, U1.39
/PRI_DBG3: P2.8, U1.59
/PRI_DBG4: P2.10, U1.54
/PRI_DBG5: P2.9, U1.113
/PRI_DBGRX: P2.5, U1.38
/PRI_DBGTX: P2.7, U1.66
/PRI_DEVCLRN: R20.1, U1.121
/PRI_DEVOE: R21.1, U1.122
/PRI_FDBG: P2.3, U1.30
/PRI_FHLT: R15.2, U1.62
/PRI_INT: R9.1, SW2.2, U1.28
/PRI_JTAGEN: P1.8, R19.1, U1.15
/PRI_NCONFIG: R22.1, SW4.2, U1.129
/PRI_NSTATUS: R16.2, U1.136
/PRI_RST: R10.1, SW3.2, U1.29
/PRI_TCK: P1.1, R13.2, U1.18
/PRI_TDI: P1.9, R11.1, U1.19
/PRI_TDO: P1.3, U1.20
/PRI_TMS: P1.5, R12.1, U1.16
/PS2_CLK: P10.5, R39.2, U6.141
/PS2_DAT: P10.1, R36.2, U6.140
/SER_CTS: U6.45, U8.16 (R_OUT)
/SER_DCD: U6.48, U8.17 (R_OUT)
/SER_DSR: U6.43, U8.18 (R_OUT)
/SER_DTR: U6.41, U8.12 (T_IN)
/SER_RTS: U6.44, U8.13 (T_IN)
/SER_RX: U6.59, U8.15 (R_OUT)
/SER_TX: U6.60, U8.14 (T_IN)
/SPI_CD0: CON3.10 (CARD_DETECT), U6.131
/SPI_CD1: CON4.10 (CARD_DETECT), U6.132
/SPI_MISO: CON2.7, CON3.7 (DAT0), CON4.7 (DAT0), R59.2, R60.2, R61.2, U6.90
/SPI_MOSI: CON2.3, CON3.2 (CMD), CON4.2 (CMD), R53.2, R54.2, R55.2, U6.91
/SPI_SCLK: CON2.5, CON3.5 (CLK), CON4.5 (CLK), R56.2, R57.2, R58.2, U6.98
/SPI_SS0: CON2.2, R50.2, U6.92
/SPI_SS1: CON3.1 (CD/DAT3), R51.2, U6.93
/SPI_SS2: CON4.1 (CD/DAT3), R52.2, U6.96
/SPI_WP0: CON3.11 (WRITE_PROTECT), U6.120
/SPI_WP1: CON4.11 (WRITE_PROTECT), U6.127
/TTL_RTS: P8.3, U6.54
/TTL_RX: P8.1, U6.88
/TTL_TX: P8.2, U6.89
/VGA_B0: R32.2, U6.50
/VGA_B1: R33.2, U6.52
/VGA_G0: R29.2, U6.58
/VGA_G1: R30.2, U6.46
/VGA_G2: R31.2, U6.47
/VGA_HS: R34.2, U6.38
/VGA_R0: R26.2, U6.55
/VGA_R1: R27.2, U6.56
/VGA_R2: R28.2, U6.57
/VGA_VS: R35.2, U6.39
unnamed: C40.1, R8.1, U1.3
unnamed: C78.1, R23.1, U6.3
unnamed: C80.1, U8.27 (V+)
unnamed: C81.1, U8.1 (C2+)
unnamed: C81.2, U8.2 (C2-)
unnamed: C82.2, U8.3 (V-)
unnamed: C83.1, U8.28 (C1+)
unnamed: C83.2, U8.24 (C1-)
unnamed: CON1.1, SW1.1
unnamed: D1.2 (A), R1.1
unnamed: D2.2 (A), R14.1
unnamed: D3.2 (A), R15.1
unnamed: D4.2 (A), R45.1
unnamed: L2.1, U1.4
unnamed: L3.1, U6.4
unnamed: P5.1, R26.1, R27.1, R28.1
unnamed: P5.2, R29.1, R30.1, R31.1
unnamed: P5.3, R32.1, R33.1
unnamed: P5.13, R34.1
unnamed: P5.14, R35.1
unnamed: P9.1, U8.6 (R_IN)
unnamed: P9.2, U8.4 (R_IN)
unnamed: P9.3, U8.11 (T_OUT)
unnamed: P9.4, U8.9 (T_OUT)
unnamed: P9.6, U8.7 (R_IN)
unnamed: P9.7, U8.10 (T_OUT)
unnamed: P9.8, U8.5 (R_IN)
unnamed: R3.1, U2.12 (VS2)
unnamed: R4.1, U2.11 (VS1)
unnamed: R5.1, U2.10 (VS0)
VAA: C9.1, C12.1, C13.1, C15.1, C18.1, C21.1, C22.1, C24.1, C25.1, C27.1, C28.1, C30.1, C31.1, C33.1, C34.1, C36.1, C37.1, C38.1, C49.1, C52.1, C53.1, C55.1, C57.1, C60.1, C61.1, C63.1, C64.1, C66.1, C67.1, C69.1, C70.1, C72.1, C73.1, C74.1, C75.1, C76.1, C84.1, CON2.4, CON3.4 (VDD), CON4.4 (VDD), P1.4, P4.4, P6.17, P7.13, P11.28, R7.2, R9.2, R10.2, R11.2, R12.2, R16.1, R17.1, R19.2, R22.2, R24.2, R25.2, R36.1, R37.2, R39.1, R42.1, R44.1, R46.1, R47.1, R48.2, R49.2, R50.1, R51.1, R52.1, R53.1, R54.1, R55.1, R56.1, R57.1, R58.1, R59.1, R60.1, R61.1, U1.9, U1.23, U1.31, U1.40, U1.49, U1.67, U1.82, U1.94, U1.103, U1.117, U1.128, U1.139, U4.3 (VDDq), U4.9 (VDDq), U4.35 (VDDq), U4.41 (VDDq), U4.49 (VDDq), U4.55 (VDDq), U4.75 (VDDq), U4.81 (VDDq), U6.9, U6.23, U6.31, U6.40, U6.49, U6.67, U6.82, U6.94, U6.103, U6.117, U6.128, U6.139, U8.22 (FORCEOFFn), U8.23 (FORCEON), U8.26 (VCC), W8.1, W10.1
VCC: C1.1, C2.1, C3.1, C4.1, C7.1, C10.1, C14.1, C19.1, C23.1, C26.1, C29.1, C32.1, C42.2, C43.1, C44.1, C45.1, C46.1, C47.1, C50.1, C54.1, C58.1, C62.1, C65.1, C68.1, C71.1, C79.2, R6.2, U1.2, U1.34, U1.35, U1.71, U1.107, U1.143, U4.1 (VDD), U4.15 (VDD), U4.29 (VDD), U4.43 (VDD), U5.1 (EN), U5.4 (VCC), U6.2, U6.34, U6.35, U6.71, U6.107, U6.143, U7.1 (EN), U7.4 (VCC), W7.1, W9.1
VEE: C5.1, C8.1, C11.1, C16.1, C20.1, C35.1, C48.1, C51.1, C56.1, C59.1, L1.2, U1.1, U1.36, U1.37, U1.51, U1.72, U1.73, U1.108, U1.109, U1.115, U1.144, U3.1, U6.1, U6.36, U6.37, U6.51, U6.72, U6.73, U6.108, U6.109, U6.115, U6.144, W1.1, W11.1

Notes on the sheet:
What're these for?

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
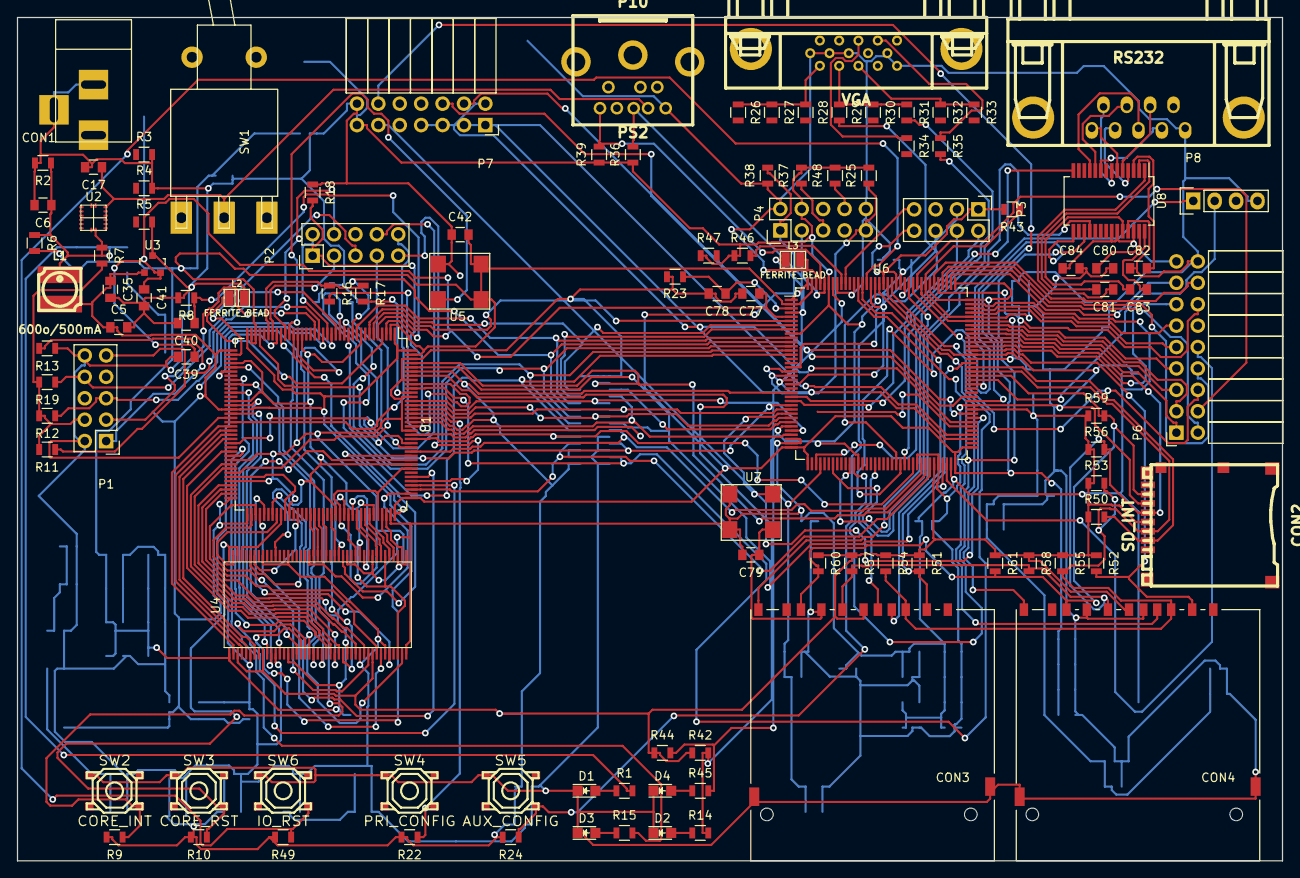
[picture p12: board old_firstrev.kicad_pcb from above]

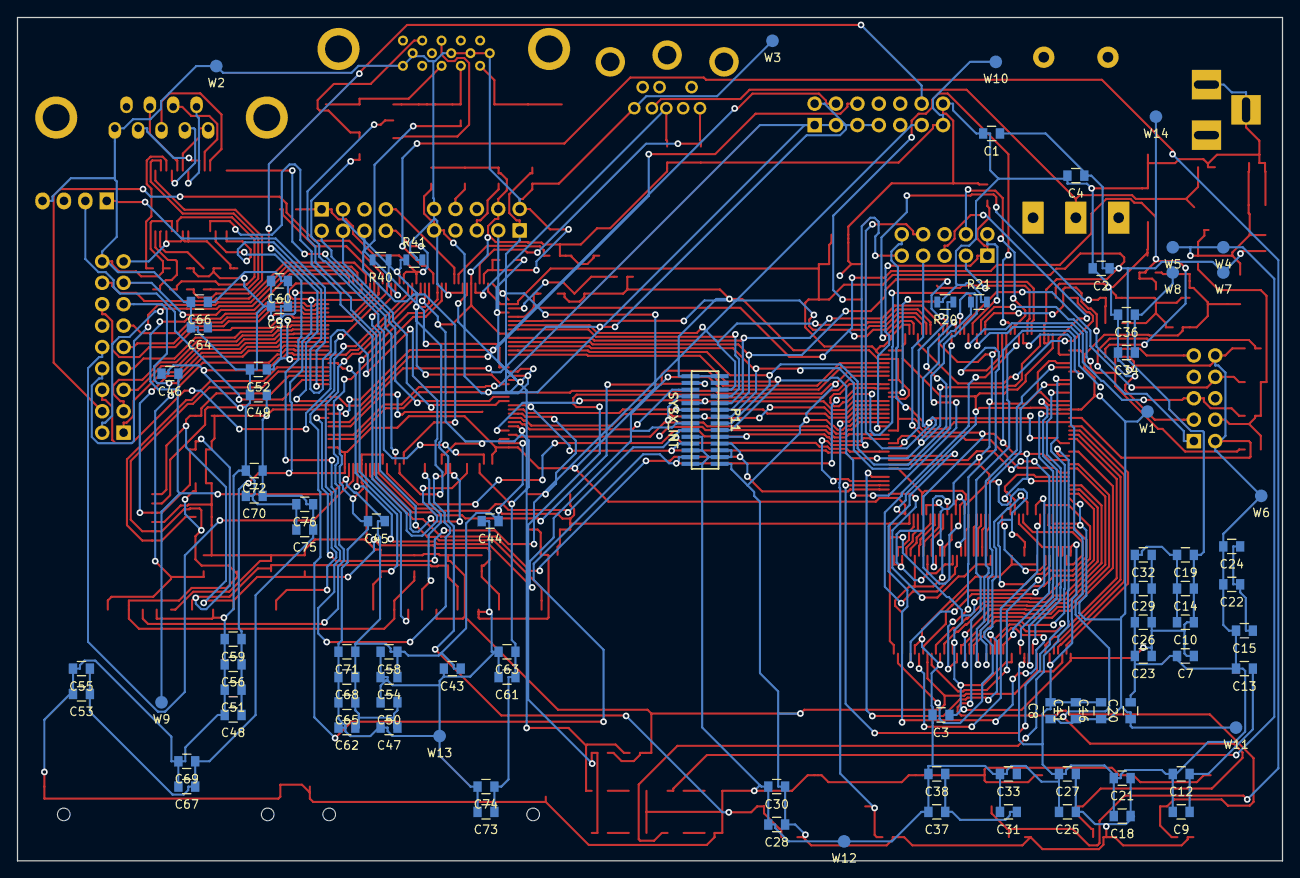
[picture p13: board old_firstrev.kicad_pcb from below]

Board: 4 copper layers, 150.1 x 100.1 mm, 195 parts (87 on the bottom side), 219 nets.

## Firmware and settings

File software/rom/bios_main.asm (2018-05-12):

; epRISC development platform - BIOS / bootloader
;
; written by John C. Lemme, jclemme (at) proportionallabs (dot) com
; this file is part of the epRISC project, released under the epRISC license - see "license.txt" for details.
;
; Bootloader for the epRISC system. Loads executables from an SD card, or launches the monitor.

!ip     h00000000
!def    BUS_BASE_ADDRESS    h2000
!def    BIOS_DISKBUF        #h3000
!def    BIOS_DISKLBL        #h3001
!def    BIOS_DISKLEN        #h3004
!def    BIOS_DISKENT        #h3005

!zone   bios_main

:entry          brch.a  a:bios

:mon_send       load.o  d:%Zz r:%GL o:#h1FF0
                push.r  s:%Zz 
                call.s  a:spi_send
                stor.o  s:%Zz r:%GL o:#h1FF1
                pops.r  d:%Zz
                rtrn.s
                
:mon_recv       call.s  a:spi_recv
                stor.o  s:%Zz r:%GL o:#h1FF1
                rtrn.s
                
:mon_scmd       load.o  d:%Zz r:%GL o:#h1FF2
                push.r  s:%Zz 
                load.o  d:%Zz r:%GL o:#h1FF3
                push.r  s:%Zz 
                call.s  a:sdc_scmd
                stor.o  s:%Zz r:%GL o:#h1FF4
                pops.r  d:%Zz
                pops.r  d:%Zz
                rtrn.s

:mon_read       load.o  d:%Zz r:%GL o:#h1FF2
                push.r  s:%Zz 
                load.o  d:%Zz r:%GL o:#h1FF3
                push.r  s:%Zz 
                call.s  a:sdc_read
                stor.o  s:%Zz r:%GL o:#h1FF4
                pops.r  d:%Zz
                pops.r  d:%Zz
                rtrn.s
                
:mon_init       call.s  a:sdc_init
                stor.o  s:%Zz r:%GL o:#h1FF5
                rtrn.s
         
;:blinky         move.v  d:%GL v:#hFF s:#h8
;                move.v  d:%GL v:#hFFFF o:%TRUE                      ; Fill value
;:.blinkloop     subr.v  d:%GL a:%GL v:#h01
;                cmpr.v  a:%GL v:#h00
;                brch.a  c:%NEQ a:.blinkloop
;                xorb.v  d:%CS a:%CS v:#h01 s:#h08                   ; Invert
;                brch.a  a:blinky                                    ; Repeat
                
:bios           move.v  d:%SP v:#h1100                              ; Put the stack somewhere handy (on the chip RAM)
                move.v  d:%GL v:#h00                                ; So that monitor control jumps work
                
;                brch.a  a:blinky
                
                call.s  a:ioc_init
                move.v  d:%Xw v:#h7FFF
                push.r  s:%Xw
                move.v  d:%Xw v:#h00
                push.r  s:%Xw
                call.s  a:ioc_send
                pops.r  d:%Xw
                pops.r  d:%Xw                                       ; Reset the I/O controller
                            
                ;call.s  a:vga_init                                  ; Start up video

                move.v  d:%Xw v:bios_str.str_welcome
                push.r  s:%Xw
                call.s  a:str_puts
                pops.r  d:%Xw                                       ; Print the welcome message

                move.v  d:%Xw v:bios_str.str_postbgn
                push.r  s:%Xw
                call.s  a:str_puts
                pops.r  d:%Xw                                       ; Announce the beginning of the POSTs

:.memtest       move.v  d:%Xw v:bios_str.str_postmem
                push.r  s:%Xw
                call.s  a:str_puts
                pops.r  d:%Xw                                       ; Test the memory
                
                move.v  d:%Xx v:#h3000
                move.v  d:%Xy v:#h3010                              ; Go to 6000 normally - cut down to speed testing
:.memloop       stor.o  r:%Xx s:%Xx 
                load.o  r:%Xx d:%Xw 
                cmpr.r  a:%Xw b:%Xx 
                brch.a  c:%NEQ a:.memchek
                move.v  d:%Zz v:#h00
                stor.o  r:%Xx s:%Zz
                addr.v  d:%Xx a:%Xx v:#h01
                cmpr.r  a:%Xx b:%Xy
                brch.a  c:%EQL a:.memchek
                brch.a  a:.memloop
                
:.memchek       move.v  d:%Xw v:bios_str.str_postnot
                cmpr.r  a:%Xx b:%Xy
                brch.a  c:%NEQ a:.memrept
                move.v  d:%Xw v:bios_str.str_postokt
:.memrept       push.r  s:%Xw
                call.s  a:str_puts
                pops.r  d:%Xw                                       ; Report result
                
                move.v  d:%Xw v:bios_str.str_postcmp
                push.r  s:%Xw
                call.s  a:str_puts
                pops.r  d:%Xw                                       ; Report end of POSTs
                                
                                
                brch.a  a:.monitor                           ; The emulator doesn't have an SD card - go right to the monitor
                                                
                                                
                move.v  d:%Xw v:#h41
                push.r  s:%Xw
                call.s  a:spi_send
                pops.r  d:%Xw                                       ; Send a garbage byte to "warm up" the SPI core
                
                move.v  d:%Xw v:bios_str.str_mountda
                push.r  s:%Xw
                call.s  a:str_puts
                pops.r  d:%Xw                                       ; Announce that we're trying to mount the first SD card
                
                call.s  a:sdc_init                                  ; Initialize the first SD card
                push.r  s:%Zz                                       ; We'll need this later
                
                move.v  d:%Xw v:bios_str.str_mountno
                cmpr.v  a:%Zz v:#hFF                                ; Did it fail?
                brch.a  c:%EQL a:.sdcprint                          ; If so, we guessed correctly
                move.v  d:%Xw v:bios_str.str_mountok                ; Passing string
:.sdcprint      push.r  s:%Xw 
                call.s  a:str_puts
                pops.r  d:%Xw                                       ; Print the correct string
                
                pops.r  d:%Zz                                       
                cmpr.v  a:%Zz v:#hFF
                brch.a  c:%EQL a:.monitor                           ; No need to look for a filesystem if the disk's dead
                       
                move.v  d:%Xw v:bios_str.str_diskbgn
                push.r  s:%Xw
                call.s  a:str_puts
                pops.r  d:%Xw                                       ; Time to look for a filesystem
                
                move.v  d:%Xw v:BIOS_DISKBUF
                push.r  s:%Xw 
                move.v  d:%Xw v:#h0
                push.r  s:%Xw 
                call.s  a:sdc_read
                pops.r  d:%Xw
                pops.r  d:%Xw                                       ; Load the first block into memory
                
                move.v  d:%Xw v:BIOS_DISKBUF
                load.o  r:%Xw d:%Zz                                 ; Check the magic
                cmpr.v  a:%Zz v:#hEA s:#h0C                         ; Is it hEA000000?
                brch.a  c:%EQL a:.gooddisk                          ; If not, continue
                move.v  d:%Xw v:bios_str.str_diskerr
                push.r  s:%Xw
                call.s  a:str_puts
                pops.r  d:%Xw                                       ; Disk is corrupt
                brch.a  a:.monitor                                  ; Give up
                
:.gooddisk      move.v  d:%Xw v:bios_str.str_disklba
                push.r  s:%Xw
                call.s  a:str_puts
                pops.r  d:%Xw                                       ; "Found disk"
                move.v  d:%Xw v:BIOS_DISKLBL
                push.r  s:%Xw
                move.v  d:%Xw v:#h0C
                push.r  s:%Xw
                call.s  a:str_putsl
                pops.r  d:%Xw
                pops.r  d:%Xw                                       ; Label
                move.v  d:%Xw v:bios_str.str_disklbb
                push.r  s:%Xw
                call.s  a:str_puts
                pops.r  d:%Xw                                       ; "at block 0"
                
                move.v  d:%Xw v:BIOS_DISKBUF
                load.o  r:%Xw d:%Zz                                 ; Check the length
                cmpr.v  a:%Zz v:#h00                                ; Are there any entries on the disk?
                brch.a  c:%NEQ a:.notempty                          ; If not, continue
                move.v  d:%Xw v:bios_str.str_diskemp
                push.r  s:%Xw
                call.s  a:str_puts
                pops.r  d:%Xw                                       ; Disk is empty
                brch.a  a:.monitor                                  ; Give up
                
:.notempty      move.v  d:%Xw v:bios_str.str_disksza
                push.r  s:%Xw
                call.s  a:str_puts
                pops.r  d:%Xw                                       ; Disk has stuff on it
                move.v  d:%Xw v:BIOS_DISKLEN
                load.o  r:%Xw d:%Zz                                 ; Check the length
                push.r  s:%Zz 
                move.v  d:%Xw v:#h02
                push.r  s:%Xw
                call.s  a:str_lnum
                pops.r  d:%Xw
                pops.r  d:%Zz                                       ; Number of entries
                move.v  d:%Xw v:bios_str.str_diskszb
                push.r  s:%Xw
                call.s  a:str_puts
                pops.r  d:%Xw                                       ; Cool cool
                
                move.v  d:%Xw v:bios_str.str_diskchs
                push.r  s:%Xw
                call.s  a:str_puts
                pops.r  d:%Xw                                       ; List the entries

                move.v  d:%Xw v:BIOS_DISKLEN
                load.o  r:%Xw d:%Xy                                 ; Get loop value
                arsl.v  d:%Xx a:%Xy v:#h02
                arsl.v  d:%Xy a:%Xy v:#h01
                addr.r  d:%Xy a:%Xy b:%Xx                           
                move.v  d:%Xx v:BIOS_DISKENT
                addr.r  d:%Xy a:%Xx b:%Xy                           ; Get start address and end address
                move.v  d:%Xz v:#h00                                ; Just for show
                
:.listloop      move.v  d:%Xw v:bios_str.str_dropspc
                push.r  s:%Xw
                call.s  a:str_puts
                pops.r  d:%Xw                                       ; "Indent"

                push.r  s:%Xz
                move.v  d:%Xw v:#h02
                push.r  s:%Xw
                call.s  a:str_lnum
                pops.r  d:%Xw
                pops.r  d:%Xz                                       ; Number
                
                move.v  d:%Xw v:bios_str.str_diskena
                push.r  s:%Xw
                call.s  a:str_puts
                pops.r  d:%Xw                                       ; "Entry"
                
                push.r  s:%Xx 
                move.v  d:%Xw v:#h0C
                push.r  s:%Xw
                call.s  a:str_putsl
                pops.r  d:%Xw
                pops.r  d:%Xx
                addr.v  d:%Xx a:%Xx v:#h03                          ; Entry string
                
                move.v  d:%Xw v:bios_str.str_diskenb
                push.r  s:%Xw
                call.s  a:str_puts
                pops.r  d:%Xw                                       ; "start"
                
                load.o  r:%Xx d:%Xw
                push.r  s:%Xw
                call.s  a:str_hnum
                pops.r  d:%Xw
                addr.v  d:%Xx a:%Xx v:#h01                          ; Start block
                
                move.v  d:%Xw v:bios_str.str_diskenc
                push.r  s:%Xw
                call.s  a:str_puts
                pops.r  d:%Xw                                       ; "length"
                
                load.o  r:%Xx d:%Xw
                push.r  s:%Xw
                call.s  a:str_hnum
                pops.r  d:%Xw
                addr.v  d:%Xx a:%Xx v:#h01                          ; Length block
                
                move.v  d:%Xw v:bios_str.str_diskend
                push.r  s:%Xw
                call.s  a:str_puts
                pops.r  d:%Xw                                       ; "load"
            
                load.o  r:%Xx d:%Xw
                push.r  s:%Xw
                call.s  a:str_hnum
                pops.r  d:%Xw
                addr.v  d:%Xx a:%Xx v:#h01                          ; Load block
                
                move.v  d:%Xw v:bios_str.str_dropnxt
                push.r  s:%Xw
                call.s  a:str_puts
                pops.r  d:%Xw                                       ; "Drop"
                
                addr.v  d:%Xz a:%Xz v:#h01                          ; Increment show number
                cmpr.r  a:%Xx b:%Xy                                 ; Are we finished?
                brch.a  c:%LOW a:.listloop                          ; If not, loop back up
                
                move.v  d:%Xw v:bios_str.str_dropnxt
                push.r  s:%Xw
                call.s  a:str_puts
                pops.r  d:%Xw                                       ; Drop down a line
                
:.chooseorp     move.v  d:%Xw v:bios_str.str_diskprm
                push.r  s:%Xw
                call.s  a:str_puts
                pops.r  d:%Xw                                       ; Prompt the user to choose an entry
                
:.chooseloop    call.s  a:ser_srcv                                  ; Get a character
                push.r  s:%Zz 
                call.s  a:ser_send
                call.s  a:vga_putc
                pops.r  d:%Zz
                
                cmpr.v  a:%Zz v:#h47                                ; Is it gonna be a number?
                brch.a  c:%HOS a:.notnum                            ; If not, run
                
:.number        subr.v  d:%Zz a:%Zz v:#h30      
                cmpr.v  a:%Zz v:#h0A
                brch.a  c:%LOW a:.goodnum
                subr.v  d:%Zz a:%Zz v:#h07 
                cmpr.v  a:%Zz v:#h0A
                brch.a  c:%LOW a:.badnum               
                cmpr.v  a:%Zz v:#h10
                brch.a  c:%LOW a:.goodnum                           ; Convert character to hex digit

:.badnum        move.v  d:%Xw v:bios_str.str_dropnxt
                push.r  s:%Xw
                call.s  a:str_puts
                pops.r  d:%Xw                                       ; Drop down a line
                brch.a  a:.chooseorp                                ; Try again
                
:.notnum        push.r  s:%Zz                                       ; We need this

                move.v  d:%Xw v:bios_str.str_dropnxt
                push.r  s:%Xw
                call.s  a:str_puts
                pops.r  d:%Xw                                       ; Drop down a line
                
                pops.r  d:%Zz                                       ; Bring it back around
                
                cmpr.v  a:%Zz v:#h4D                                ; Is it "M"?
                brch.a  c:%EQL a:.monitor                           ; If so, jump to the monitor
                brch.a  a:.chooseorp                                ; Else, try again
                
:.goodnum       push.r  s:%Zz

                move.v  d:%Xw v:bios_str.str_dropnxt
                push.r  s:%Xw
                call.s  a:str_puts
                pops.r  d:%Xw                                       ; Drop down a line
                
                move.v  d:%Xw v:bios_str.str_disklod
                push.r  s:%Xw
                call.s  a:str_puts
                pops.r  d:%Xw                                       
                pops.r  d:%Zz                                       ; Loading message
                
                arsl.v  d:%Xx a:%Zz v:#h02
                arsl.v  d:%Zz a:%Zz v:#h01
                addr.r  d:%Zz a:%Zz b:%Xx
                move.v  d:%Xx v:BIOS_DISKENT
                addr.r  d:%Yw a:%Xx b:%Zz                           ; Calculate the entry location
                
                load.o  r:%Yw d:%Xx o:#h03                          ; Start block
                load.o  r:%Yw d:%Xy o:#h04                          ; Length block
                load.o  r:%Yw d:%Xz o:#h05                          ; Load block              
                
:.loadloop      push.r  s:%Xz
                push.r  s:%Xx
                call.s  a:sdc_read
                pops.r  d:%Xx
                pops.r  d:%Xz                                       ; Load the first block

                cmpr.v  a:%Zz v:#h00
                brch.a  c:%NEQ a:.monitor
                
                addr.v  d:%Xx a:%Xx v:#h01                          ; Increment current block
                addr.v  d:%Xz a:%Xz v:#h80                          ; Increment load address
                subr.v  d:%Xy a:%Xy v:#h01                          ; Decrement length
                
                cmpr.v  a:%Xy v:#h00                                ; Are we done?
                brch.a  c:%NEQ a:.loadloop                          ; If not, loop back up
                
:.runit         call.s  a:vga_sclr                                  ; Clear the screen
                load.o  r:%Yw d:%Xz o:#h05                          ; Load block
                ;push.r  s:%Xz
                ;call.s  a:str_hnum
                ;pops.r  d:%Xz
                brch.o  r:%Xz                                       ; Run the program
                
:.monitor       move.v  d:%Xw v:bios_str.str_monitor
                push.r  s:%Xw
                call.s  a:str_puts  
                pops.r  d:%Xw                                       ; We're just going to immediately enter the monitor
                
                brch.a  a:lemon_entr
                


!zone   bios_str

:.str_welcome   !str "epRISC Bootloader v3.4\n\rcopyright 2015-2017 Proportional Labs\n\r\n\r\0"
:.str_mountda   !str "Attempting to mount SD card in slot A...\n\r\0"
:.str_mountdb   !str "Attempting to mount SD card in slot B...\n\r\0"
:.str_mountok   !str "  SD card mounted successfully.\n\r\n\r\0"
:.str_mountno   !str "  Error mounting SD card.\n\r\n\r\0"

:.str_diskbgn   !str "Fetching disk info...\n\r\0"
:.str_diskerr   !str "  Disk appears to be corrupt.\n\r\n\r\0"
:.str_disklba   !str "  Found disk '\0"
:.str_disklbb   !str "' at block 0.\n\r\0"
:.str_diskemp   !str "  Disk appears to be empty.\n\r\n\r\0"
:.str_disksza   !str "  Found \0"
:.str_diskszb   !str " entries on disk.\n\r\n\r\0"
:.str_diskchs   !str "Available entries:\n\r\0"
:.str_diskena   !str ": Entry '\0"
:.str_diskenb   !str "': start \0"
:.str_diskenc   !str ", length \0"
:.str_diskend   !str ", load \0"
:.str_diskprm   !str "Select an entry to execute, or type 'M' to enter the monitor: \0"
:.str_disklod   !str "  Loading entry...\n\r\n\r\0"

:.str_postbgn   !str "Starting POSTs...\n\r\0"
:.str_postmem   !str "  Memory          \0"
:.str_postser   !str "  UART            \0"
:.str_postspi   !str "  SPI             \0"
:.str_postsys   !str "  sysX Bus        \0"
:.str_postioc   !str "  I/O Controller  \0"
:.str_postokt   !str "OK\n\r\0"
:.str_postnot   !str "FAIL\n\r\0"
:.str_postgud   !str "  POST successful.\n\r\n\r\0"
:.str_postfal   !str "  POST unsuccessful.\n\r\n\r\0"
:.str_postcmp   !str "  POSTs complete.\n\r\n\r\0"

:.str_monitor   !str "Entering monitor...\n\r\n\r\0"
:.str_dropnxt   !str "\n\r\0"
:.str_dropspc   !str "  \0"

!include    "bios_bus.asm"
!include    "bios_uart_fast.asm"
!include    "bios_spi.asm"
!include    "bios_string.asm"
!include    "bios_sdcard.asm"
!include    "bios_video.asm"
!include    "bios_debug.asm"
!include    "lemon_main.asm"

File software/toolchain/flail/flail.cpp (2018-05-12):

#include <iostream>
#include <cstdint>
#include <cstdlib>
#include <cstring>
#include <fstream>
#include <string>
#include <vector>

#include <unistd.h>
#include <ncurses.h>

#include "obj_dir/VepRISC_coreEmu.h"

// Gotta be global
VepRISC_coreEmu* machine;

void resetMachine();

int main(int argc, char **argv)
{
    machine = new VepRISC_coreEmu();
    
    //Machine variables
    int delay = 0;
    int cycnt = 0;
    bool singleStep = false, stepTaken = true, coreRunning = true, controlled = true;
    
    //UART variables
    std::vector<char> inputBuffer;
    
    //NCurses veriables
    int termY = 0, termX = 0;
    int termMaxY, termMaxX;
    char keyIn = 0;
    bool commandMode = false;
    
    int sendLastState = 1, recvCount = 1, recvSending = 0;
    
    if(argc > 1)
    {
        bool padding = true;
        
        uint32_t* memory = (uint32_t*)malloc(sizeof(uint32_t) * 32768);
        memset(memory, ' ', sizeof(uint32_t) * 32768);
    
        std::ifstream bFile;
        bFile.open(argv[1], std::ios::binary | std::ios::in);
        
        if(bFile.fail())
        {
            std::cout << "ff";
            bFile.close();
        }
        
        int count = 0, ptr, rptr = 0, size = 32768;
        uint32_t tmpA, tmpB, tmpC, tmpD;
        
        while(count < size && bFile.good())
        {
            bFile.read((char*)(memory+count), sizeof(uint32_t));
            count++;
        }
        
        for(ptr=0;ptr<count;ptr++)
        {
            tmpA = (memory[ptr] & 0xFF000000) >> 24;
            tmpB = (memory[ptr] & 0x00FF0000) >> 16;
            tmpC = (memory[ptr] & 0x0000FF00) >> 8;
            tmpD = (memory[ptr] & 0x000000FF);
            memory[ptr] = (tmpA) + (tmpB<<8) + (tmpC<<16) + (tmpD<<24);
        }
        
        for(ptr=0;ptr<count;ptr++)
        {
            if(memory[ptr] != 0)
                padding = false;
                
            if(!padding)
            {
                machine->epRISC_coreEmu__DOT__machine__DOT__tbsdram__DOT__rContents[rptr+0x4000] = memory[ptr];
                rptr++;
            }
        }
        
        bFile.close();
    }
   
    if(argc > 2)
    {
        uint32_t* memory = (uint32_t*)malloc(sizeof(uint32_t) * 8242880);
        memset(memory, ' ', sizeof(uint32_t) * 8242880);
    
        std::ifstream bFile;
        bFile.open(argv[2], std::ios::binary | std::ios::in);
        
        if(bFile.fail())
        {
            std::cout << "ff";
            bFile.close();
        }
        
        int count = 0, ptr = 0, size = 8242880;
        uint32_t tmpA, tmpB, tmpC, tmpD;
        
        while(count < size && bFile.good())
        {
            bFile.read((char*)(memory+count), sizeof(uint32_t));
            count++;
        }
        
        for(ptr=0;ptr<count;ptr++)
        {
            tmpA = (memory[ptr] & 0xFF000000) >> 24;
            tmpB = (memory[ptr] & 0x00FF0000) >> 16;
            tmpC = (memory[ptr] & 0x0000FF00) >> 8;
            tmpD = (memory[ptr] & 0x000000FF);
            memory[ptr] = (tmpA) + (tmpB<<8) + (tmpC<<16) + (tmpD<<24);
        }
        
        for(ptr=0;ptr<count;ptr++)
            machine->epRISC_coreEmu__DOT__machine__DOT__tbsdram__DOT__rContents[ptr+0x8000] = memory[ptr];
        
        bFile.close();
    }
    
    //Set up NCurses
    initscr();
    getmaxyx(stdscr, termMaxY, termMaxX);
    
    WINDOW* termwin = newwin(termMaxY-3, termMaxX, 0, 0);
    WINDOW* taskwin = newwin(3, termMaxX, termMaxY-3, 0);
    
    raw();
    cbreak();
    noecho();
    nodelay(termwin, TRUE);
    scrollok(termwin, TRUE);
    idlok(termwin, TRUE);
    start_color();
    
    init_pair(1, COLOR_BLACK, COLOR_WHITE);
    init_pair(2, COLOR_WHITE, COLOR_BLACK);
    
    wattron(termwin, COLOR_PAIR(2));
    wattron(taskwin, COLOR_PAIR(1));
    
    //Reset the core
    resetMachine();
    
    //The mainloop
    while(coreRunning)
    {       
        keyIn = wgetch(termwin);
         
        if(keyIn != ERR)
        {
            if(commandMode)
            {   
                commandMode = false;
                
                switch(keyIn)
                {
                    case('q'): coreRunning = false; break;
                    case('l'): controlled = !controlled; break;
                    case('p'): singleStep = !singleStep; break;
                    case('c'): stepTaken = (singleStep) ? false : true; break;
                    case('r'): resetMachine(); break;
                    case('d'): delay += 50; break;
                    case('f'): delay = 150; break;
                    case('g'): delay -= (delay > 0) ? 50 : 0; break;
                    case('`'): inputBuffer.push_back('`'); break;
                }
            }
            else if(keyIn != '`')
            {
                switch(keyIn)
                {
                    // epRISC programs look for Minicom control characters, so we need to convert Ncurses-style codes
                    case(0x0A): inputBuffer.push_back(0x0D); break; // Enter
                    case(0x7F): inputBuffer.push_back(0x08); break; // Backspace
                    default: inputBuffer.push_back(keyIn); break;
                }
            }
            else
            {
                commandMode = true;
            }
        }
        
        if(!singleStep || (singleStep && !stepTaken))
        {
            //Tick tock
            machine->iBoardClock = !machine->iBoardClock;
            machine->eval();
            
            //If a send was requested...
            if(((machine->epRISC_coreEmu__DOT__controller__DOT__uart__DOT__rControl & 0xC0) > 0) && sendLastState == 0)
            {
                switch(machine->epRISC_coreEmu__DOT__controller__DOT__uart__DOT__rDataIn & 0xFF)
                {
                    case(0x0A): waddch(termwin, '\n'); break;
                    default: waddch(termwin, machine->epRISC_coreEmu__DOT__controller__DOT__uart__DOT__rDataIn & 0xFF); break;
                }
                
                wrefresh(termwin);
                sendLastState = 1;
            }
            
            if((machine->epRISC_coreEmu__DOT__controller__DOT__uart__DOT__rControl & 0xC0) == 0)
                sendLastState = 0;
                
            //If a receive was requested and there's data to send...
            if(recvSending == 0 && inputBuffer.size() > 0)
            {
                recvSending = 1;
                recvCount = 0;
            }
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

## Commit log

2016-10-19 Initial file upload
    [board_auxiliary.sch, board_clock.sch, board_connectivity.sch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]
2016-10-27 Interrupt behavior better defined
2016-11-14 Interrupts will be finished later - using a simpler version for now
2017-01-10 Fixed register swap issue
    [core_v5r0.v]
2017-01-11 Fixed issue with pop load instruction
    [core_v5r0.v]
2017-01-11 Actually fixed it this time
    [core_v5r0.v]
2017-01-11 Interrupts are a go
2017-01-17 Documentation cleanup, assembly/sysX spec, added spasm to repo
2017-02-10 Bus controller done/not debugged, some core bugs
    [core_v5r0.v]
2017-03-13 Bugfixes and I/O controller setup
    [core_v5r0.v]
2017-03-16 Hopefully all working now
    [epRISC_Auxiliary.smp_dump.txt, stp1.stp]
2017-03-18 UART is also working now
2017-03-18 v5 assembly def. is done, spasm ported
2017-04-03 Fixed the messed up tree
    [stp1.stp]
2017-06-01 Video working now
    [epRISC_Auxiliary.smp_dump.txt]
2018-05-12 flail work and ext2 support beginnings
    [assignment.csv, clock.csv, exploration_summary.csv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]
